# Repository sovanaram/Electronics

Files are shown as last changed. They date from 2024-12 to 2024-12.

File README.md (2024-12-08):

# Isolated Pure Sine Wave Single Phase Inverter using SPWM
this topic is about How to make Inverter by your self and These are the steps to makes it:
1, Researching theories of Inverter 
2, Select Topology (DCDC Converter stage, Inverter stage)
3, Calculating DCDC Converter and Inverter
4, Calculating Transformer and Inductors of DCDC Converter
5, Design Transformer and Inductors 
6, Design schematic and PCB 
7, Installing Hardware 
8, Select electronic switches(MOSFETs and DIODEs)
9, Select Controller
10, Programming and choose the types of Closed loop Control Methods, Filter
11, Testing Hardware

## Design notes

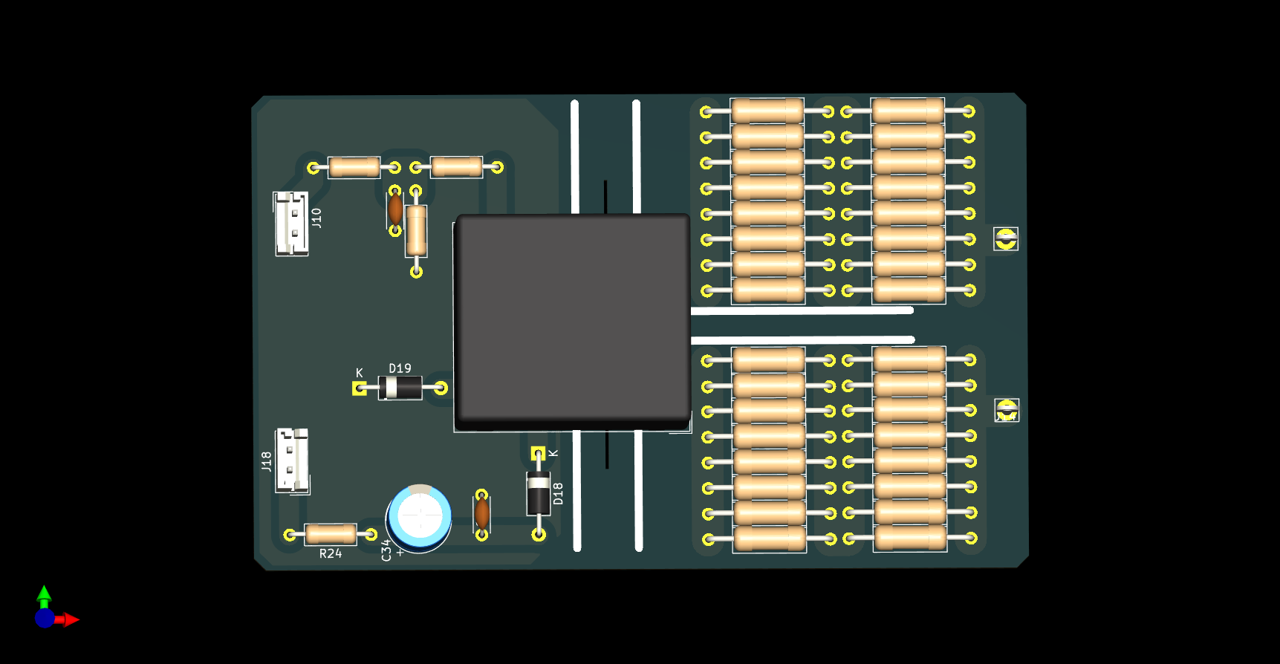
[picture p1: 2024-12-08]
Voltage Sensor/Voltage Sensor.png

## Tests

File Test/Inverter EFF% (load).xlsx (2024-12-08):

No. | Vin(V) | Iin(A) | Pin(W) | Vout(V) | Iout(A) | Pout(W) | PF | EFF%
1 | 50.5 | 0.51 | 25.755 | 224 | 0 | 0 | 1 | 0
2 | 50.23 | 0.79 | 39.6817 | 224 | 0.04553571429 | 10.2 | 1 | 25.70454391 |  |  |  |  | No. | Vo(AC) | Po(INV) W | Pin(INV) W | PF | Pin(DC) W | Vin(DC) V | EFF%(INV) | EFF%(DC) | EFF%(Tot)
3 | 49.97 | 0.81 | 40.4757 | 224.5 | 0.05033407572 | 11.3 | 1 | 27.91798536 |  |  |  | No Load | 1 | 224 | 0 | 6.8 | 0 | 27.28 | 49.6 | 0 | 24.92668622 | 0
4 | 49.95 | 0.87 | 43.4565 | 224.53 | 0.08301785953 | 18.64 | 1 | 42.89346818 |  |  |  | pho.CH+LED | 2 | 224 | 11.5 | 18.8 | 0.538 | 40.919 | 49.3 | 61.17021277 | 45.94442679 | 28.10430362
5 | 49.92 | 1.01 | 50.4192 | 224.52 | 0.09665063246 | 21.7 | 1 | 43.03915969 |  |  |  | LCR meter | 3 | 224.5 | 13.5 | 20.8 | 0.72 | 42.398 | 49.3 | 64.90384615 | 49.05891787 | 31.84112458
6 | 49.88 | 1.08 | 53.8704 | 224.36 | 0.113210911 | 25.4 | 1 | 47.15019751 |  |  |  | PC Addap | 4 | 224.53 | 17.6 | 24.8 | 0.859 | 47.821 | 49.3 | 70.96774194 | 51.86006148 | 36.8039146
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

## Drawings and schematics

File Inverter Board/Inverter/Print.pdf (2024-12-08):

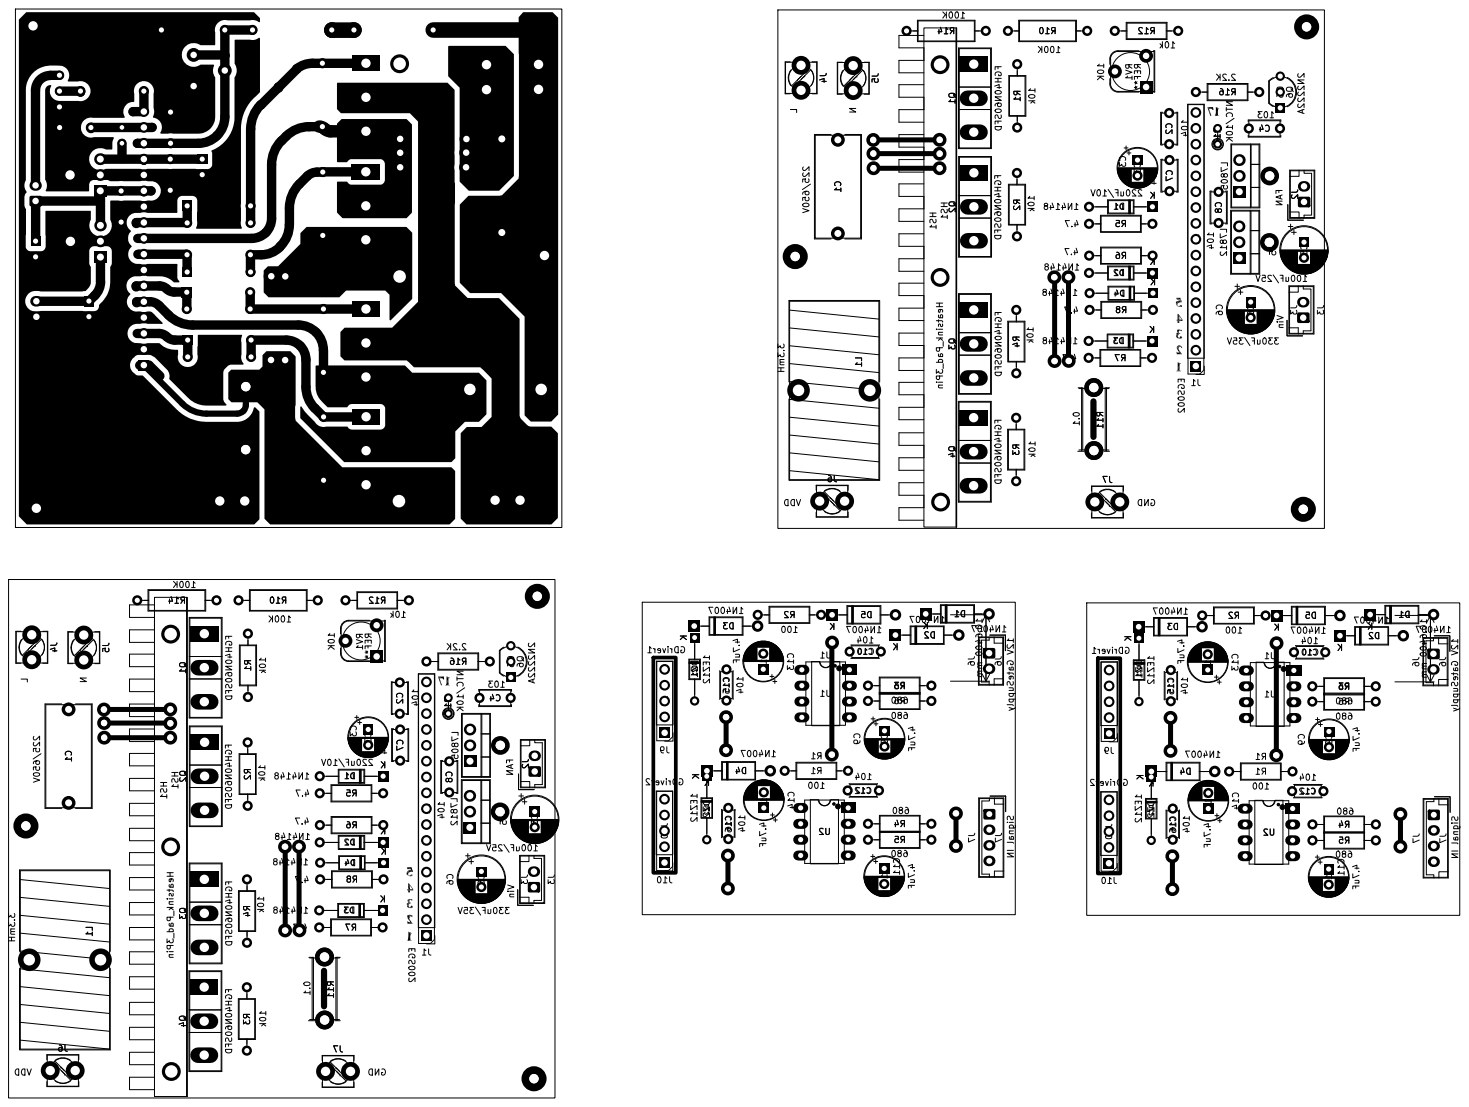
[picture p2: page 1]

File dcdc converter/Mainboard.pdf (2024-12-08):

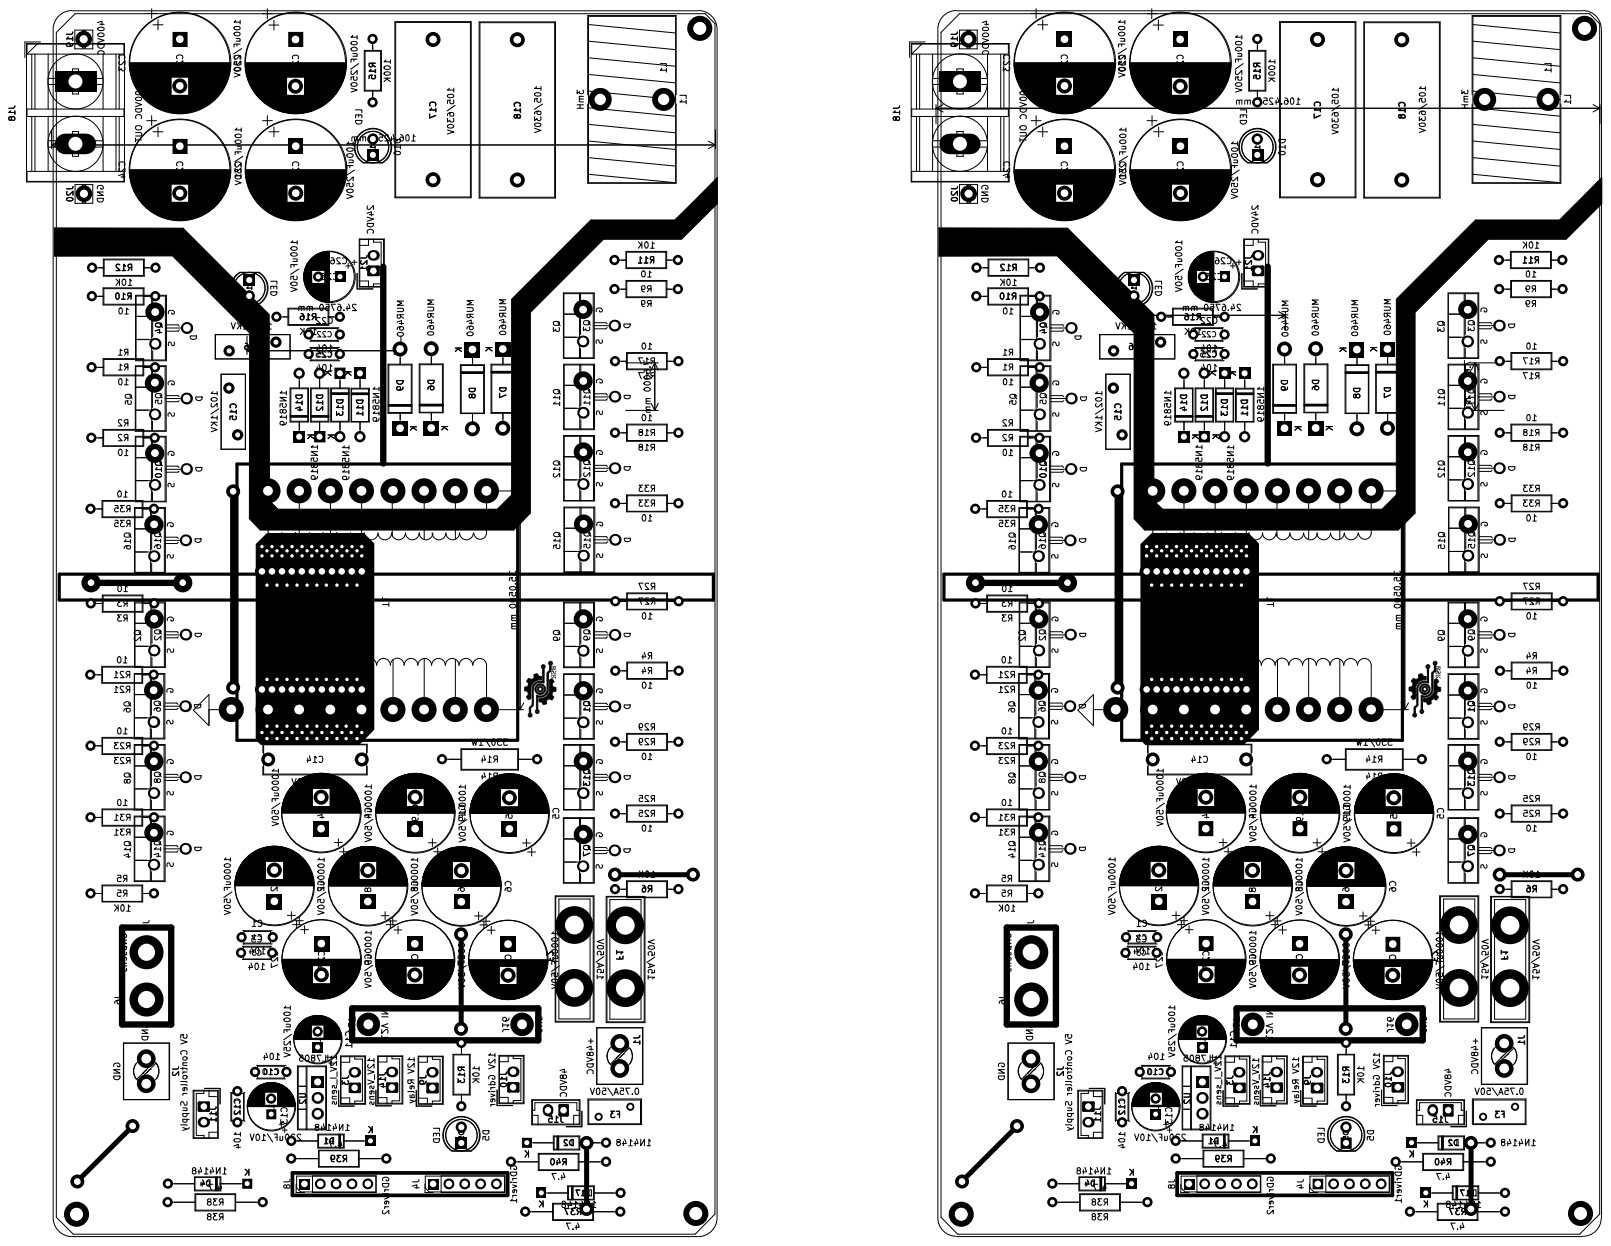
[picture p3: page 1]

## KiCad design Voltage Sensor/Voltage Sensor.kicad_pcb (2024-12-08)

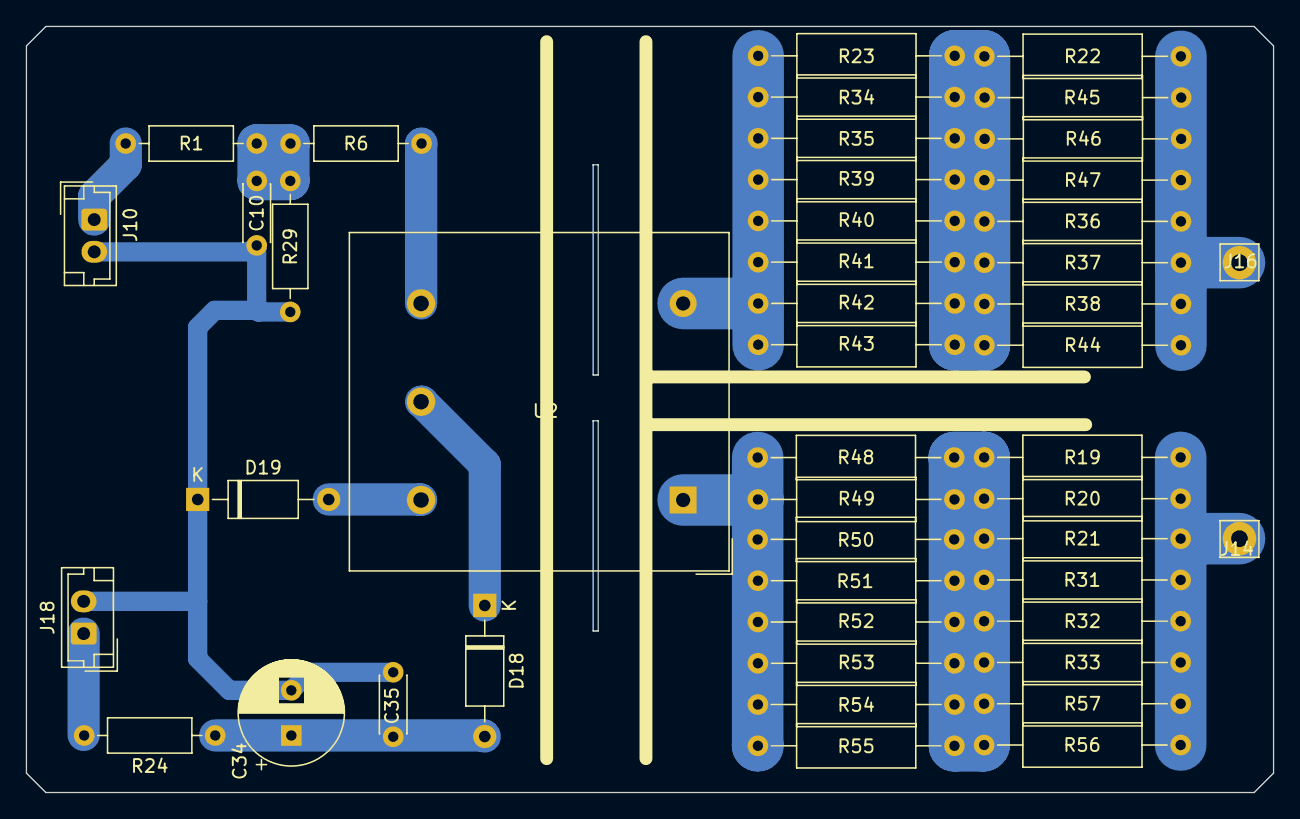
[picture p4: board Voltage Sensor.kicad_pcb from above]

Board: 2 copper layers, 96.7 x 59.4 mm, 46 parts (0 on the bottom side), 4 nets.

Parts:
C10: 102; C_Disc_D4.3mm_W1.9mm_P5.00mm
C34: 100uF/25; CP_Radial_D8.0mm_P3.50mm
C35: 104; C_Disc_D4.3mm_W1.9mm_P5.00mm
D18: 1N4007; D_A-405_P10.16mm_Horizontal
D19: D; D_A-405_P10.16mm_Horizontal
J10: V_sens; JST_EH_B2B-EH-A_1x02_P2.50mm_Vertical
J14: 400VDC; Pin_D1.3mm_L11.3mm_W2.8mm_Flat
J16: GND; Pin_D1.3mm_L11.3mm_W2.8mm_Flat
J18: 12V_Vsens; JST_EH_B2B-EH-A_1x02_P2.50mm_Vertical
R1: 330; R_Axial_DIN0207_L6.3mm_D2.5mm_P10.16mm_Horizontal
R6, R29: 1K; R_Axial_DIN0207_L6.3mm_D2.5mm_P10.16mm_Horizontal
R19, R20, R21, R22, R23, R31, R32, R33, R34, R35, R36, R37, R38, R39, R40, R41, R42, R43, R44, R45, R46, R47, R48, R49, R50, R51, R52, R53, R54, R55, R56, R57: 100k; R_Axial_DIN0309_L9.0mm_D3.2mm_P15.24mm_Horizontal
R24: 100; R_Axial_DIN0207_L6.3mm_D2.5mm_P10.16mm_Horizontal
U2: LV25-P; LEM_LV25-P

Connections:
+12V: J18.1, R24.2
/+400VDC: J14.1, R19.2, R20.2, R21.2, R31.2, R32.2, R33.2, R56.2, R57.2
GND: C10.2, C34.2, C35.2, D19.1 (K), J10.2, J18.2, R29.1
GND1: J16.1, R22.2, R36.2, R37.2, R38.2, R44.2, R45.2, R46.2, R47.2

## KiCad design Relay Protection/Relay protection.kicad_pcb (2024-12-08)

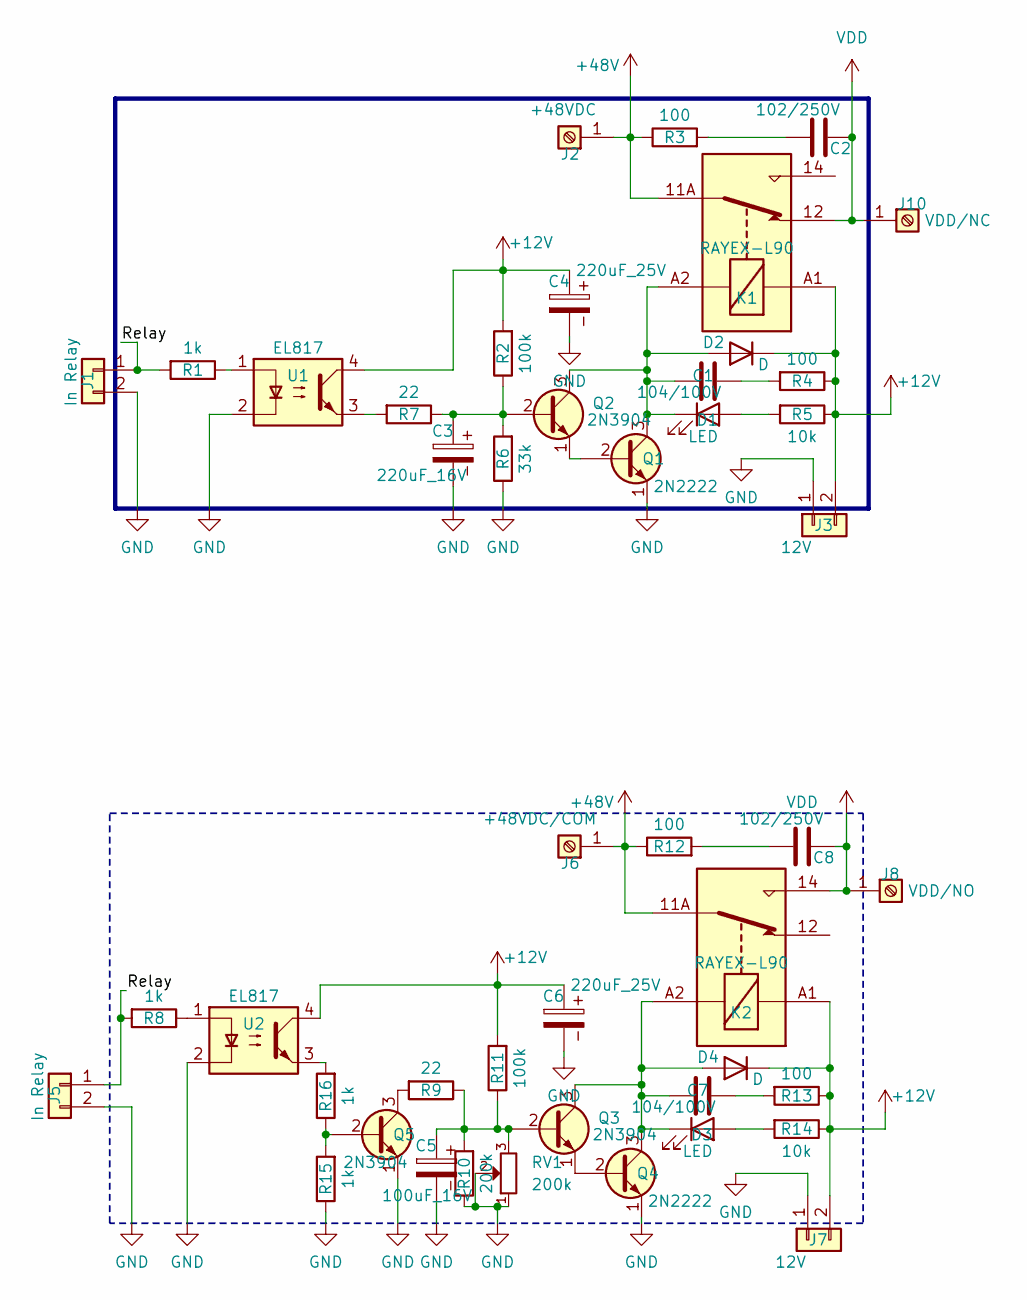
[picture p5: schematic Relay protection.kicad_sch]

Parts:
C1, C7: 104/100V; C_Disc_D6.0mm_W2.5mm_P5.00mm
C2, C8: 102/250V; Fuse_BelFuse_0ZRE0016FF_L9.9mm_W3.8mm
C3: 220uF_16V; CP_Radial_D6.3mm_P2.50mm
C4, C6: 220uF_25V; CP_Radial_D6.3mm_P2.50mm
C5: 100uF_16V; CP_Radial_D6.3mm_P2.50mm
D1, D3: LED; LED_D5.0mm_Clear
D2, D4: D; D_A-405_P10.16mm_Horizontal
J1, J5: In Relay; JST_EH_B2B-EH-A_1x02_P2.50mm_Vertical
J2: +48VDC; TerminalBlock_MetzConnect_360291_1x01_Horizontal_ScrewM3.0_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
J3, J7: 12V; JST_EH_B2B-EH-A_1x02_P2.50mm_Vertical
J6: +48VDC/COM; TerminalBlock_MetzConnect_360291_1x01_Horizontal_ScrewM3.0_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
J8: VDD/NO; TerminalBlock_MetzConnect_360291_1x01_Horizontal_ScrewM3.0_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
J10: VDD/NC; TerminalBlock_MetzConnect_360291_1x01_Horizontal_ScrewM3.0_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
K1, K2: RAYEX-L90; Relay_SPDT_RAYEX-L90
Q1, Q4: 2N2222; TO-92_Inline_Wide
Q2, Q3, Q5: 2N3904; TO-92L_Inline_Wide
R1, R8, R15, R16: 1k; R_Axial_DIN0207_L6.3mm_D2.5mm_P10.16mm_Horizontal
R2, R11: 100k; R_Axial_DIN0207_L6.3mm_D2.5mm_P10.16mm_Horizontal
R3, R4, R12, R13: 100; R_Axial_DIN0207_L6.3mm_D2.5mm_P10.16mm_Horizontal
R5, R14: 10k; R_Axial_DIN0207_L6.3mm_D2.5mm_P10.16mm_Horizontal
R6: 33k; R_Axial_DIN0207_L6.3mm_D2.5mm_P10.16mm_Horizontal
R7, R9: 22; R_Axial_DIN0207_L6.3mm_D2.5mm_P10.16mm_Horizontal
R10: 200k; R_Axial_DIN0207_L6.3mm_D2.5mm_P10.16mm_Horizontal
RV1: 200k; Potentiometer_RM065
U1, U2: EL817; DIP-4_W7.62mm

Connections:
+12V: C4.1, C6.1, D2.1 (K), D4.1 (K), J3.2, J7.2, K1.A1, K2.A1, R2.2, R4.1, R5.1, R11.2, R13.1, R14.1, U1.4, U2.4
+48V: J2.1, J6.1, K1.11A, K1.11B, K2.11A, K2.11B, R3.1, R12.1
/Relay: J1.1, J5.1, R1.2, R8.2
GND: C3.2, C4.2, C5.2, C6.2, J1.2, J3.1, J5.2, J7.1, Q1.1 (E), Q4.1 (E), Q5.1 (E), R6.1, R10.1, R15.1, RV1.1, RV1.2, U1.2, U2.2
unnamed: C1.1, R4.2
unnamed: C2.1, R3.2
unnamed: C7.1, R13.2
unnamed: C8.1, R12.2
unnamed: D1.2 (A), R5.2
unnamed: C1.2, D1.1 (K), D2.2 (A), K1.A2, Q1.3 (C), Q2.3 (C)
unnamed: D3.2 (A), R14.2
unnamed: C7.2, D3.1 (K), D4.2 (A), K2.A2, Q3.3 (C), Q4.3 (C)
unnamed: Q1.2 (B), Q2.1 (E)
unnamed: C3.1, Q2.2 (B), R2.1, R6.2, R7.1
unnamed: C5.1, Q3.2 (B), R9.1, R10.2, R11.1, RV1.3
unnamed: Q3.1 (E), Q4.2 (B)
unnamed: Q5.2 (B), R15.2, R16.1
unnamed: Q5.3 (C), R9.2
unnamed: R1.1, U1.1
unnamed: R7.2, U1.3
unnamed: R8.1, U2.1
unnamed: R16.2, U2.3
VDD: C2.2, C8.2, J8.1, J10.1, K1.12, K2.14

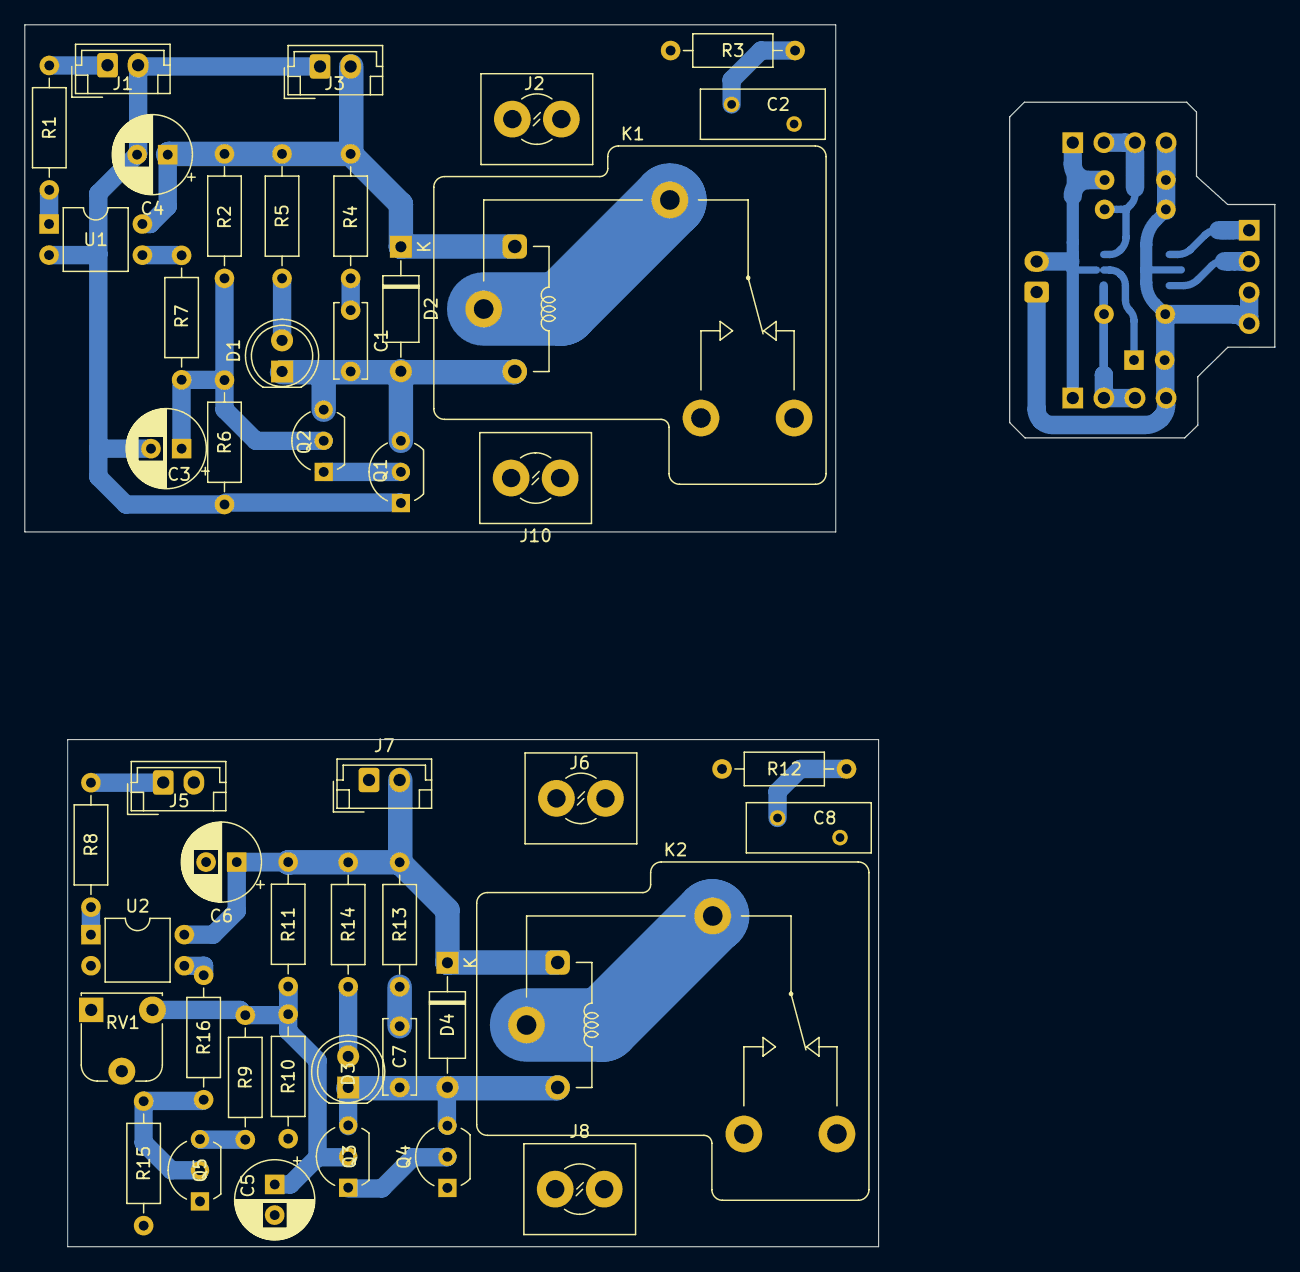
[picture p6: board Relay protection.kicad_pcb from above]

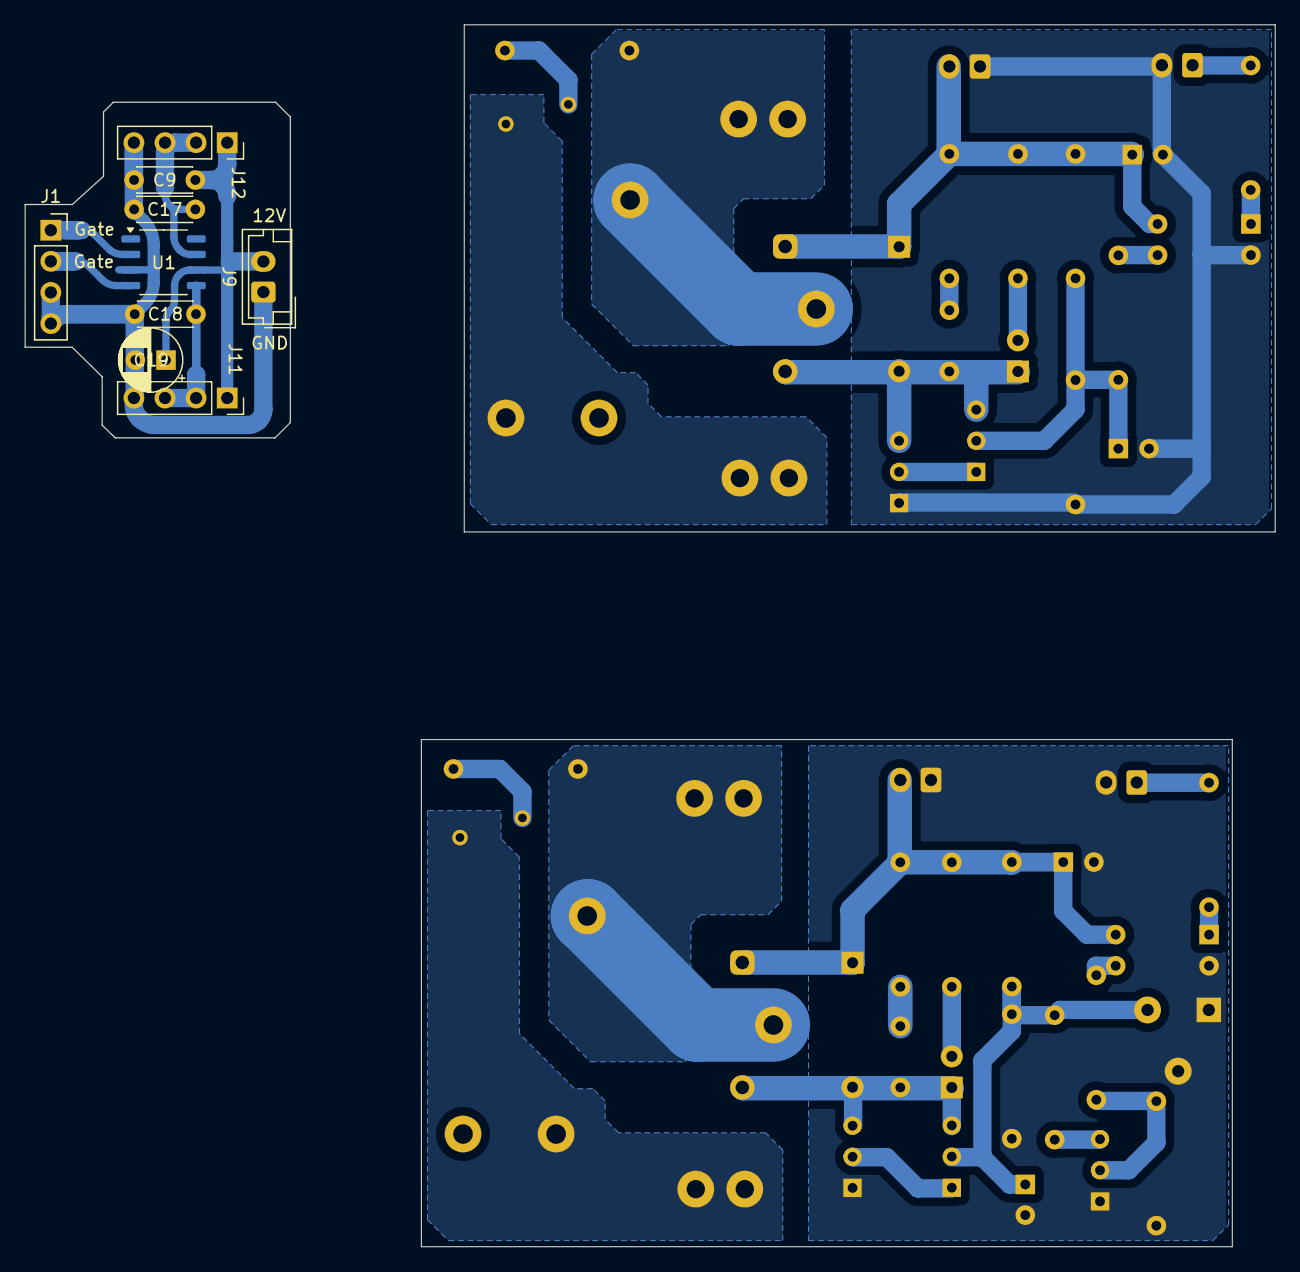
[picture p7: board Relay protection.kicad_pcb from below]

Board: 2 copper layers, 102.1 x 99.8 mm, 55 parts (9 on the bottom side), 23 nets.

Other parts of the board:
C9: 104; C_Disc_D4.3mm_W1.9mm_P5.00mm
C17, C18: 102; C_Disc_D4.3mm_W1.9mm_P5.00mm
C19: 10uF/50V; CP_Radial_D5.0mm_P2.50mm
J1#2, J11, J12: Conn_01x04; PinSocket_1x04_P2.54mm_Vertical
J9: 12V Gdriver; JST_EH_B2B-EH-A_1x02_P2.50mm_Vertical
U1#2: IRS4427S; SSOP-8_3.9x5.05mm_P1.27mm

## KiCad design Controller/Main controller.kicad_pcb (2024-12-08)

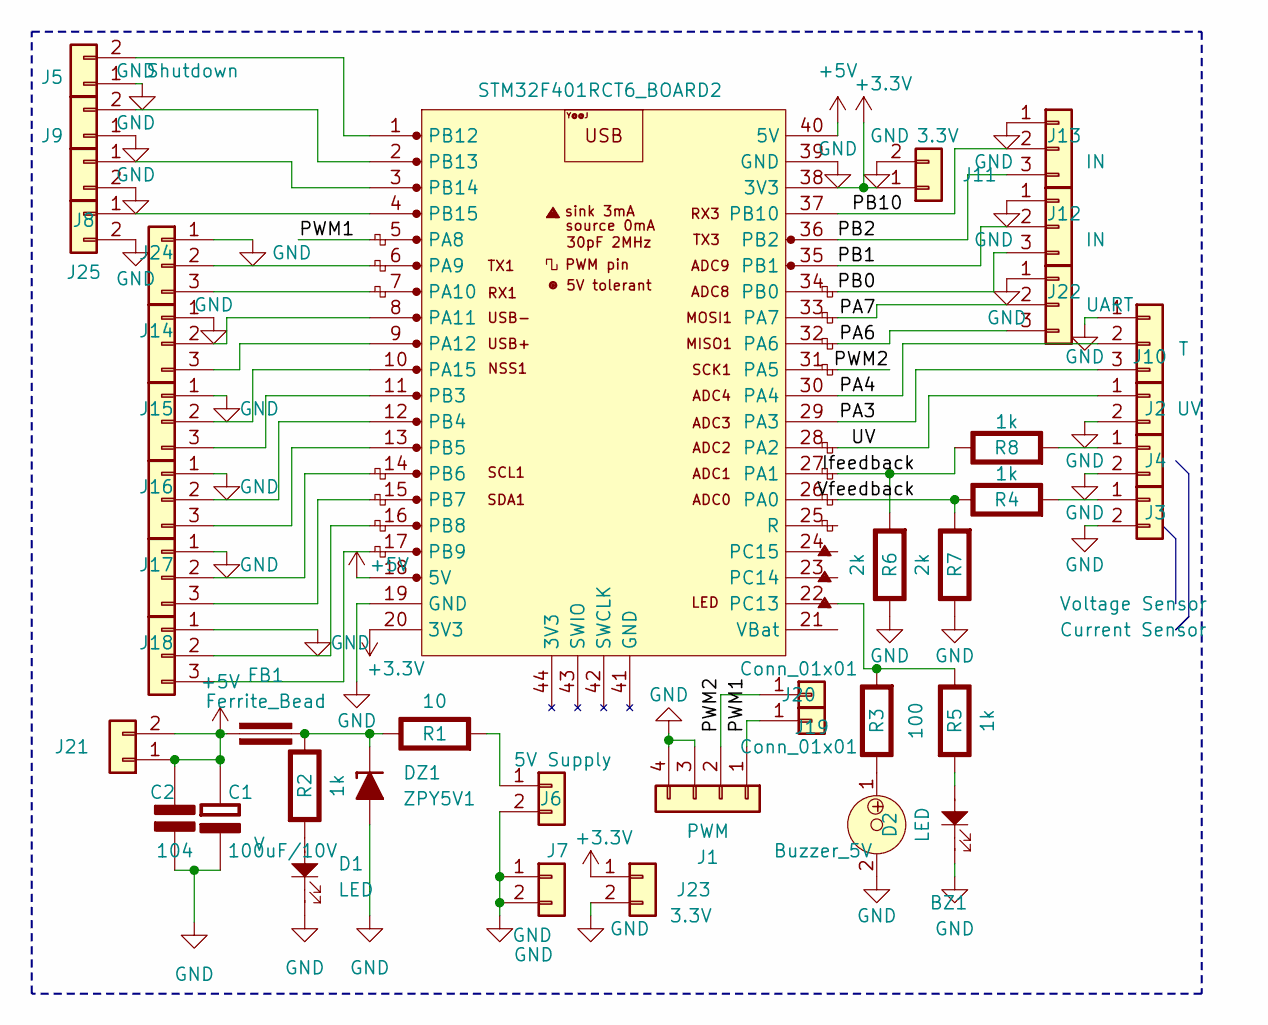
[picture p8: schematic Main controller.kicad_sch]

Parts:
BZ1: Buzzer_5V; MagneticBuzzer_ProSignal_ABT-410-RC
C1: 100uF/10V; CP_Radial_D7.5mm_P2.50mm; Rating V
C2: 104; C_Disc_D5.0mm_W2.5mm_P5.00mm; Rating V
D1, D2: LED; LED_D5.0mm
DZ1: ZPY5V1; D_DO-34_SOD68_P7.62mm_Horizontal
FB1: Ferrite_Bead; L_Axial_L7.0mm_D3.3mm_P5.08mm_Vertical_Fastron_MICC
J1: PWM; JST_EH_B4B-EH-A_1x04_P2.50mm_Vertical
J2: UV; JST_EH_B2B-EH-A_1x02_P2.50mm_Vertical
J3: Voltage Sensor; JST_EH_B2B-EH-A_1x02_P2.50mm_Vertical
J4: Current Sensor; JST_EH_B2B-EH-A_1x02_P2.50mm_Vertical
J5: Shutdown; JST_EH_B2B-EH-A_1x02_P2.50mm_Vertical
J6: 5V Supply; JST_EH_B2B-EH-A_1x02_P2.50mm_Vertical
J7: GND; JST_EH_B2B-EH-A_1x02_P2.50mm_Vertical
J8, J9, J21, J25: JST_EH_B2B-EH-A_1x02_P2.50mm_Vertical
J10: T; JST_EH_B3B-EH-A_1x03_P2.50mm_Vertical
J11, J23: 3.3V; JST_EH_B2B-EH-A_1x02_P2.50mm_Vertical
J12, J13: IN; JST_EH_B3B-EH-A_1x03_P2.50mm_Vertical
J14, J15, J16, J17, J18, J24: JST_EH_B3B-EH-A_1x03_P2.50mm_Vertical
J19, J20: Conn_01x01; PinSocket_1x01_P2.54mm_Vertical
J22: UART; JST_EH_B3B-EH-A_1x03_P2.50mm_Vertical
R1: 10; R_Axial_DIN0207_L6.3mm_D2.5mm_P10.16mm_Horizontal; Rating W
R2, R4, R5, R8: 1k; R_Axial_DIN0207_L6.3mm_D2.5mm_P10.16mm_Horizontal; Rating W
R3: 100; R_Axial_DIN0207_L6.3mm_D2.5mm_P10.16mm_Horizontal; Rating W
R6, R7: 2k; R_Axial_DIN0207_L6.3mm_D2.5mm_P10.16mm_Horizontal; Rating W
STM32F401RCT6_BOARD2: STM32F401RCT6_BOARD1

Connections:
+5V: C1.1 (+), C2.1 (+), FB1.1, J21.1, J21.2, STM32F401RCT6_BOARD2.18 (5V), STM32F401RCT6_BOARD2.40 (5V)
/Ifeedback: R6.2 (-), R8.1 (+), STM32F401RCT6_BOARD2.27 (PA1)
/PA3: J10.3, STM32F401RCT6_BOARD2.29 (PA3)
/PA4: J10.2, STM32F401RCT6_BOARD2.30 (PA4)
/PA6: J22.3, STM32F401RCT6_BOARD2.32 (PA6)
/PA7: J22.2, STM32F401RCT6_BOARD2.33 (PA7)
/PB0: J12.3, STM32F401RCT6_BOARD2.34 (PB0)
/PB1: J12.2, STM32F401RCT6_BOARD2.35 (PB1)
/PB2: J13.3, STM32F401RCT6_BOARD2.36 (PB2)
/PB10: J13.2, STM32F401RCT6_BOARD2.37 (PB10)
/PWM1: J1.1, J19.1, STM32F401RCT6_BOARD2.5 (PA8)
/PWM2: J1.2, J20.1, STM32F401RCT6_BOARD2.31 (PA5)
/UV: J2.1, STM32F401RCT6_BOARD2.28 (PA2)
/Vfeedback: R4.1 (+), R7.2 (-), STM32F401RCT6_BOARD2.26 (PA0)
GND: BZ1.2, C1.2 (-), C2.2 (-), D1.1, D2.1, DZ1.2 (A), J1.3, J1.4, J2.2, J3.2, J4.2, J5.1, J6.2, J7.1, J7.2, J8.2, J9.1, J10.1, J11.2, J12.1, J13.1, J14.1, J15.1, J16.1, J17.1, J18.1, J22.1, J23.2, J24.1, J25.2, R6.1 (+), R7.1 (+), STM32F401RCT6_BOARD2.19 (GND), STM32F401RCT6_BOARD2.39 (GND)
unnamed: DZ1.1 (K), FB1.2, R1.1 (+), R2.1 (+)
unnamed: J3.1, R4.2 (-)
unnamed: J4.1, R8.2 (-)
unnamed: J5.2, STM32F401RCT6_BOARD2.1 (PB12)
unnamed: J6.1, R1.2 (-)
unnamed: J8.1, STM32F401RCT6_BOARD2.3 (PB14)
unnamed: J9.2, STM32F401RCT6_BOARD2.2 (PB13)
unnamed: J14.2, STM32F401RCT6_BOARD2.8 (PA11)
unnamed: J14.3, STM32F401RCT6_BOARD2.9 (PA12)
unnamed: J15.2, STM32F401RCT6_BOARD2.10 (PA15)
unnamed: J15.3, STM32F401RCT6_BOARD2.11 (PB3)
unnamed: J16.2, STM32F401RCT6_BOARD2.12 (PB4)
unnamed: J16.3, STM32F401RCT6_BOARD2.13 (PB5)
unnamed: J17.2, STM32F401RCT6_BOARD2.14 (PB6)
unnamed: J17.3, STM32F401RCT6_BOARD2.15 (PB7)
unnamed: J18.2, STM32F401RCT6_BOARD2.16 (PB8)
unnamed: J18.3, STM32F401RCT6_BOARD2.17 (PB9)
unnamed: J24.2, STM32F401RCT6_BOARD2.6 (PA9)
unnamed: J24.3, STM32F401RCT6_BOARD2.7 (PA10)
unnamed: J25.1, STM32F401RCT6_BOARD2.4 (PB15)
unnamed: D1.2, R2.2 (-)
unnamed: BZ1.1, R3.1 (+)
unnamed: R3.2 (-), R5.1 (+), STM32F401RCT6_BOARD2.22 (PC13)
unnamed: D2.2, R5.2 (-)

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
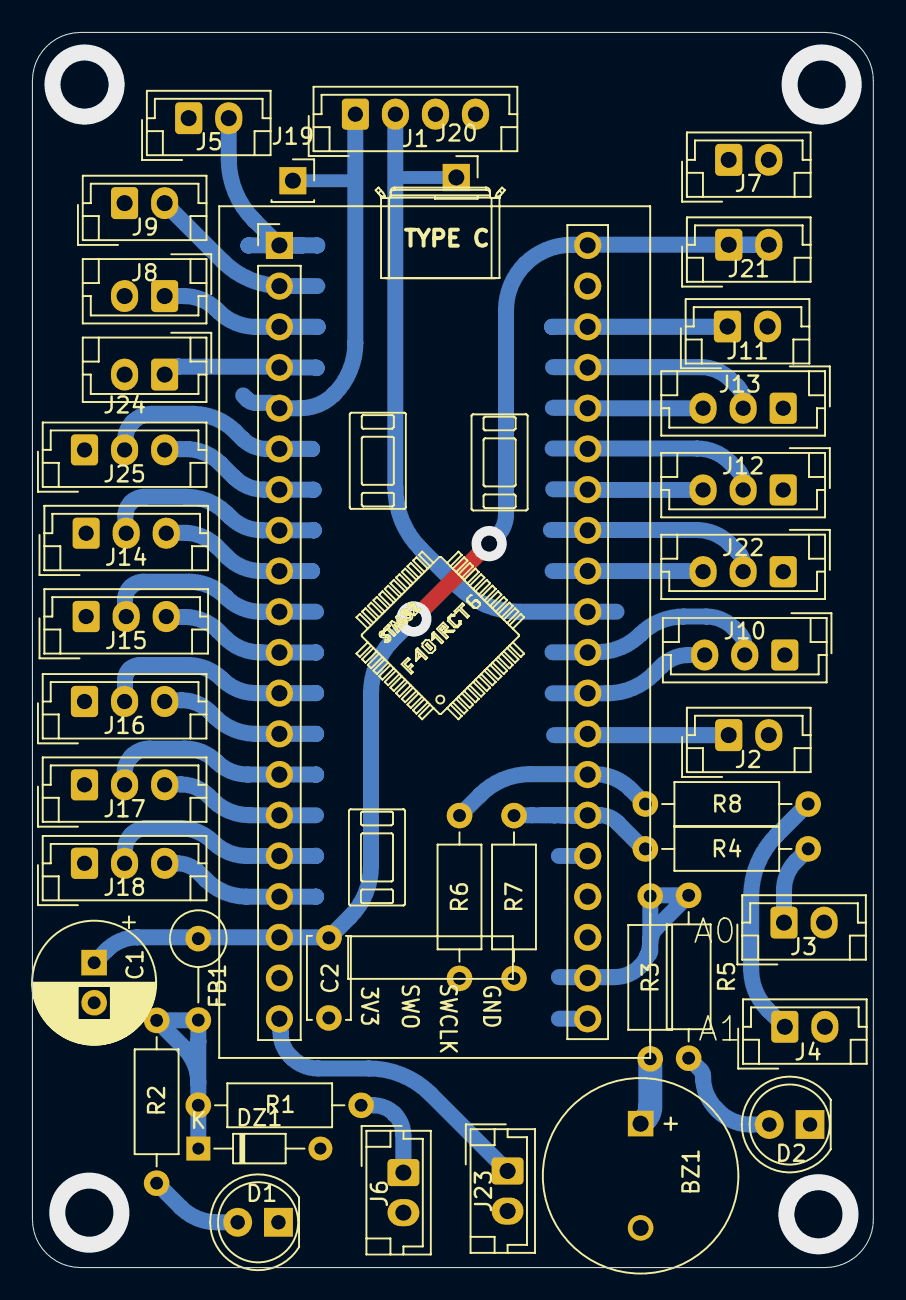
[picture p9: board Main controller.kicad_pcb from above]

Board: 2 copper layers, 52.5 x 77.1 mm, 41 parts (0 on the bottom side), 41 nets.

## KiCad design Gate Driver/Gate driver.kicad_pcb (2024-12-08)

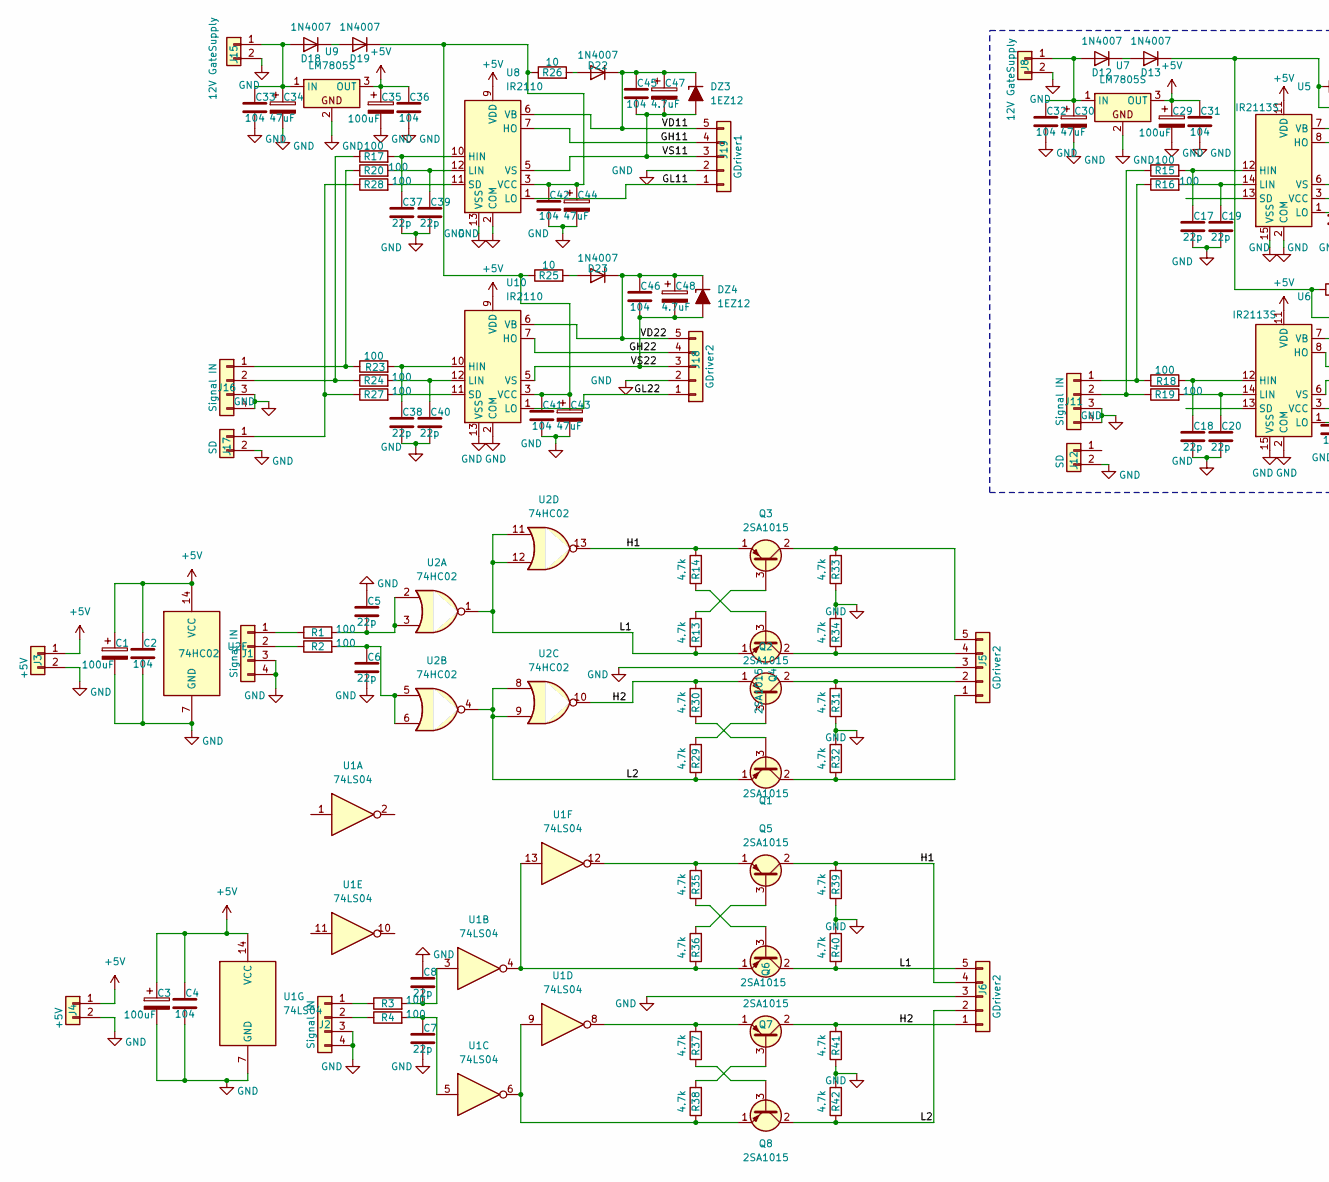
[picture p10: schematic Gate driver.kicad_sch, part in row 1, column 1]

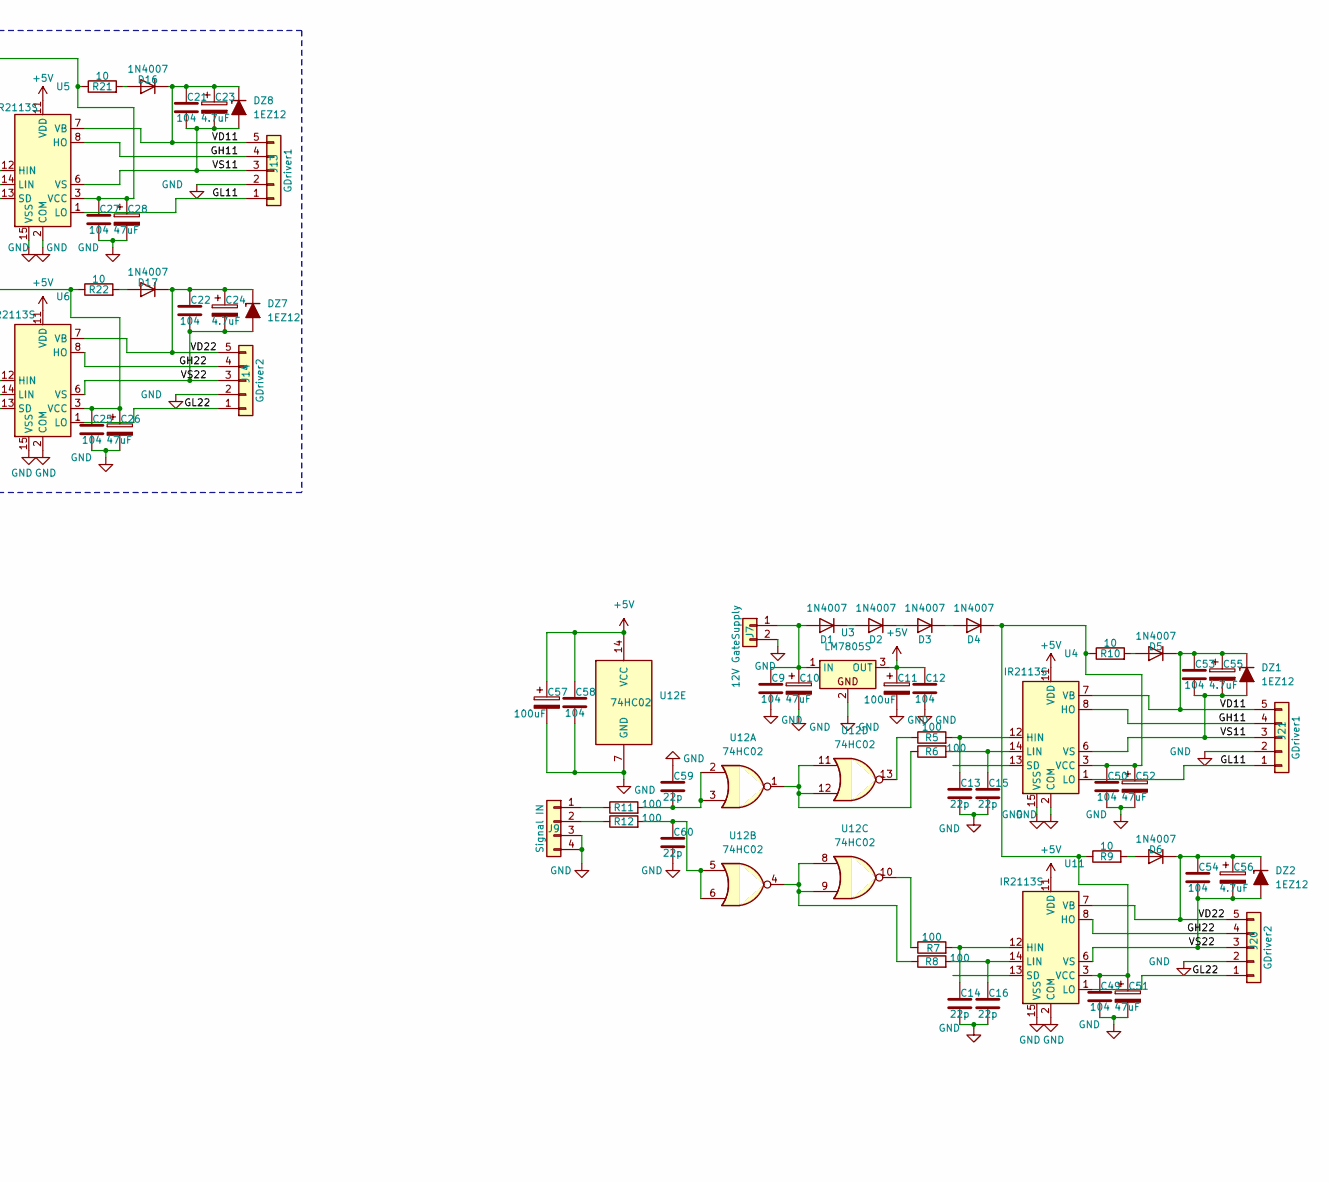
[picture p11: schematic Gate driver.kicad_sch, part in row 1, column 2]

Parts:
C1, C3, C11, C29, C35, C57: 100uF; CP_Radial_D6.3mm_P2.50mm
C2, C4, C9, C12, C21, C22, C25, C27, C31, C32, C33, C36, C41, C42, C45, C46, C49, C50, C53, C54, C58: 104; C_Disc_D4.3mm_W1.9mm_P5.00mm
C5, C6, C7, C8, C13, C14, C15, C16, C17, C18, C19, C20, C37, C38, C39, C40, C59, C60: 22p; C_Disc_D4.3mm_W1.9mm_P5.00mm
C10, C26, C28, C30, C34, C43, C44, C51, C52: 47uF; CP_Radial_D6.3mm_P2.50mm
C23, C24, C47, C48, C55, C56: 4.7uF; CP_Radial_D6.3mm_P2.50mm
D1, D2, D3, D4, D5, D6, D12, D13, D16, D17, D18, D19, D22, D23: 1N4007; D_SMA
DZ1, DZ2, DZ3, DZ4, DZ7, DZ8: 1EZ12; D_DO-34_SOD68_P10.16mm_Horizontal
J1, J2, J9, J11, J16: Signal IN; JST_EH_B4B-EH-A_1x04_P2.50mm_Vertical
J3, J4: +5V; JST_EH_B2B-EH-A_1x02_P2.50mm_Vertical
J5, J6, J14, J18, J20: GDriver2; PinSocket_1x05_P2.54mm_Vertical
J7, J8, J15: 12V GateSupply; JST_EH_B2B-EH-A_1x02_P2.50mm_Vertical
J12, J17: SD; JST_EH_B2B-EH-A_1x02_P2.50mm_Vertical
J13, J19, J21: GDriver1; PinSocket_1x05_P2.54mm_Vertical
Q1, Q2, Q3, Q4, Q5, Q6, Q7, Q8: 2SA1015; TO-92_Inline_Wide_ECB
R1, R2, R3, R4, R5, R6, R7, R8, R11, R12, R15, R16, R17, R18, R19, R20, R23, R24, R27, R28: 100; R_Axial_DIN0207_L6.3mm_D2.5mm_P10.16mm_Horizontal
R9, R10, R21, R22, R25, R26: 10; R_1210_3225Metric_Pad1.30x2.65mm_HandSolder
R13, R14, R29, R30, R31, R32, R33, R34, R35, R36, R37, R38, R39, R40, R41, R42: 4.7k; R_Axial_DIN0207_L6.3mm_D2.5mm_P10.16mm_Horizontal
U1: 74LS04; DIP-14_W7.62mm_LongPads
U2, U12: 74HC02; DIP-14_W7.62mm_LongPads
U3, U7: LM7805S; TO-252-2
U4, U5, U6, U11: IR2113S; SOIC-16W_7.5x10.3mm_P1.27mm
U8, U10: IR2110; DIP-14_W7.62mm
U9: LM7805S; TO-263-3_TabPin2

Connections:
+5V: C1.1, C2.1, C3.1, C4.1, C11.1, C12.1, C29.1, C31.1, C35.1, C36.1, C57.1, C58.1, J3.1, J4.1, U1.14 (VCC), U2.14 (VCC), U3.3 (OUT), U4.11 (VDD), U5.11 (VDD), U6.11 (VDD), U7.3 (OUT), U8.9 (VDD), U9.3 (OUT), U10.9 (VDD), U11.11 (VDD), U12.14 (VCC)
/GH11: J13.4, J19.4, J21.4, U4.8 (HO), U5.8 (HO), U8.7 (HO)
/GH22: J14.4, J18.4, J20.4, U6.8 (HO), U10.7 (HO), U11.8 (HO)
/GL11: J13.1, J19.1, J21.1, U4.1 (LO), U5.1 (LO), U8.1 (LO)
/GL22: J14.1, J18.1, J20.1, U6.1 (LO), U10.1 (LO), U11.1 (LO)
/H1: J6.4, Q3.1 (E), Q5.2 (C), R14.2, R39.2, U2.13
/H2: J6.1, Q2.1 (E), Q7.2 (C), R30.2, R41.2, U2.10
/L1: J6.5, Q4.1 (E), Q6.2 (C), R13.1, R40.1, U2.1, U2.11, U2.12
/L2: J6.2, Q1.1 (E), Q8.2 (C), R29.1, R42.1, U2.4, U2.8, U2.9
/VD11: C21.1, C23.1, C45.1, C47.1, C53.1, C55.1, D5.1 (K), D16.1 (K), D22.1 (K), DZ1.1 (K), DZ3.1 (K), DZ8.1 (K), J13.5, J19.5, J21.5, U4.7 (VB), U5.7 (VB), U8.6 (VB)
/VS11: C21.2, C23.2, C45.2, C47.2, C53.2, C55.2, DZ1.2 (A), DZ3.2 (A), DZ8.2 (A), J13.3, J19.3, J21.3, U4.6 (VS), U5.6 (VS), U8.5 (VS)
GND: C1.2, C2.2, C3.2, C4.2, C5.1, C6.2, C7.2, C8.1, C9.2, C10.2, C11.2, C12.2, C13.2, C14.2, C15.2, C16.2, C17.2, C18.2, C19.2, C20.2, C25.2, C26.2, C27.2, C28.2, C29.2, C30.2, C31.2, C32.2, C33.2, C34.2, C35.2, C36.2, C37.2, C38.2, C39.2, C40.2, C41.2, C42.2, C43.2, C44.2, C49.2, C50.2, C51.2, C52.2, C57.2, C58.2, C59.1, C60.2, J1.3, J1.4, J2.3, J2.4, J3.2, J4.2, J5.3, J6.3, J7.2, J8.2, J9.3, J9.4, J11.3, J11.4, J12.2, J13.2, J14.2, J15.2, J16.3, J16.4, J17.2, J18.2, J19.2, J20.2, J21.2, R31.1, R32.2, R33.1, R34.2, R39.1, R40.2, R41.1, R42.2, U1.7 (GND), U2.7 (GND), U3.2, U4.2 (COM), U4.15 (VSS), U5.2 (COM), U5.15 (VSS), U6.2 (COM), U6.15 (VSS), U7.2, U8.2 (COM), U8.13 (VSS), U9.2, U10.2 (COM), U10.13 (VSS), U11.2 (COM), U11.15 (VSS), U12.7 (GND)
unnamed: C5.2, R1.2, U2.2, U2.3
unnamed: C6.1, R2.2, U2.5, U2.6
unnamed: C7.1, R4.2, U1.5
unnamed: C8.2, R3.2, U1.3
unnamed: C59.2, R11.2, U12.2, U12.3
unnamed: C60.1, R12.2, U12.5, U12.6
unnamed: C9.1, C10.1, D1.2 (A), J7.1, U3.1 (IN)
unnamed: D1.1 (K), D2.2 (A)
unnamed: D2.1 (K), D3.2 (A)
unnamed: D3.1 (K), D4.2 (A)
unnamed: C49.1, C50.1, C51.1, C52.1, D4.1 (K), R9.1, R10.1, U4.3 (VCC), U11.3 (VCC)
unnamed: D5.2 (A), R10.2
unnamed: D6.2 (A), R9.2
unnamed: C30.1, C32.1, D12.2 (A), J8.1, U7.1 (IN)
unnamed: D12.1 (K), D13.2 (A)
unnamed: D16.2 (A), R21.2
unnamed: D17.2 (A), R22.2
unnamed: C33.1, C34.1, D18.2 (A), J15.1, U9.1 (IN)
unnamed: D18.1 (K), D19.2 (A)
unnamed: D22.2 (A), R26.2
unnamed: D23.2 (A), R25.2
unnamed: J1.1, R1.1
unnamed: J1.2, R2.1
unnamed: J2.1, R3.1
unnamed: J2.2, R4.1
unnamed: J5.1, Q1.2 (C), R32.1
unnamed: J5.2, Q2.2 (C), R31.2
unnamed: J5.4, Q4.2 (C), R34.1
unnamed: J5.5, Q3.2 (C), R33.2
unnamed: J9.1, R11.1
unnamed: J9.2, R12.1
unnamed: J11.1, R16.1, R18.1
unnamed: J11.2, R15.1, R19.1
unnamed: J16.1, R20.1, R23.1
unnamed: J16.2, R17.1, R24.1
unnamed: J17.1, R27.1, R28.1
unnamed: Q1.3 (B), R30.1
unnamed: Q2.3 (B), R29.2
unnamed: Q3.3 (B), R13.2
unnamed: Q4.3 (B), R14.1
unnamed: Q5.3 (B), R36.2
unnamed: Q5.1 (E), R35.2, U1.12
unnamed: Q6.3 (B), R35.1
unnamed: Q6.1 (E), R36.1, U1.4, U1.13
unnamed: Q7.3 (B), R38.2
unnamed: Q7.1 (E), R37.2, U1.8
unnamed: Q8.3 (B), R37.1
unnamed: Q8.1 (E), R38.1, U1.6, U1.9
unnamed: R5.1, U12.13
unnamed: R6.1, U12.1, U12.11, U12.12
unnamed: R7.1, U12.10
unnamed: R8.1, U12.4, U12.8, U12.9
unnamed: C13.1, R5.2, U4.12 (HIN)
unnamed: C15.1, R6.2, U4.14 (LIN)
unnamed: C17.1, R15.2, U5.12 (HIN)
unnamed: C19.1, R16.2, U5.14 (LIN)
unnamed: C18.1, R18.2, U6.12 (HIN)
unnamed: C20.1, R19.2, U6.14 (LIN)
unnamed: C37.1, R17.2, U8.10 (HIN)
unnamed: C39.1, R20.2, U8.12 (LIN)
unnamed: R28.2, U8.11 (SD)
unnamed: C38.1, R23.2, U10.10 (HIN)
unnamed: C40.1, R24.2, U10.12 (LIN)
unnamed: R27.2, U10.11 (SD)
unnamed: C14.1, R7.2, U11.12 (HIN)
unnamed: C16.1, R8.2, U11.14 (LIN)

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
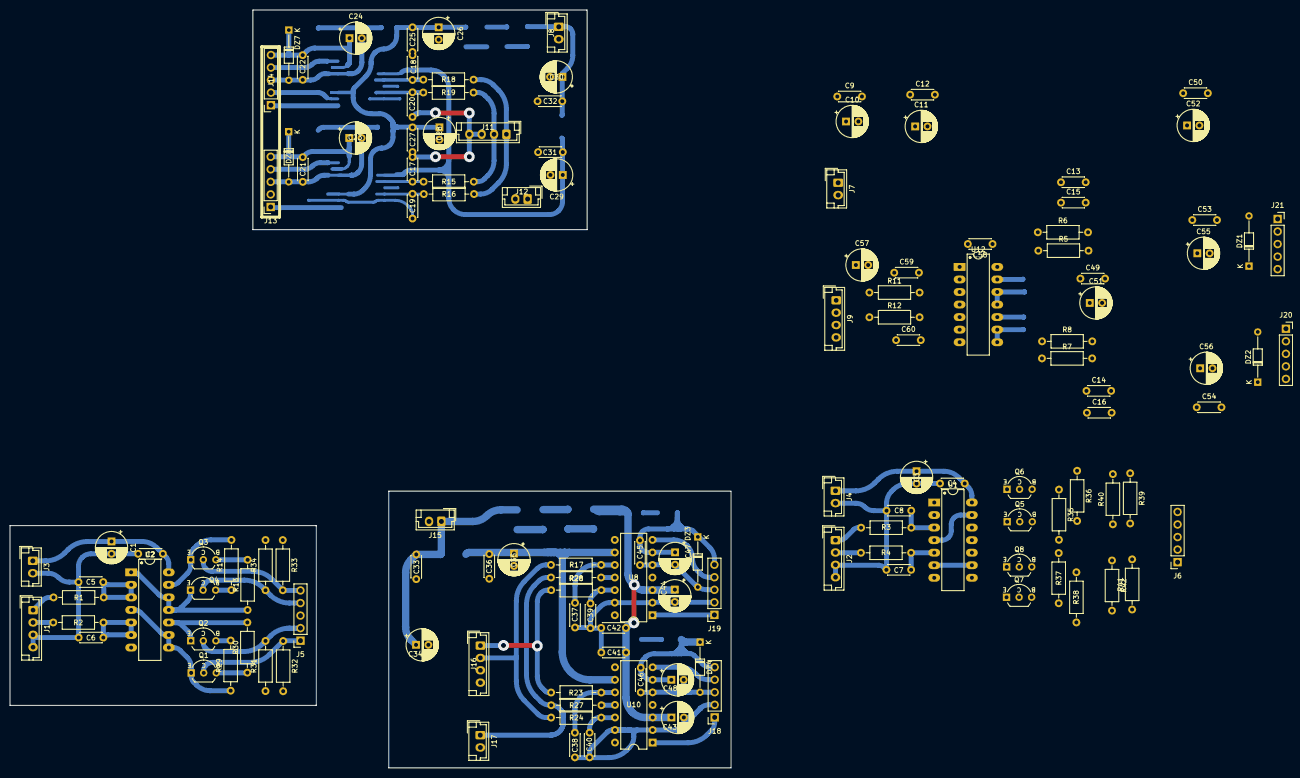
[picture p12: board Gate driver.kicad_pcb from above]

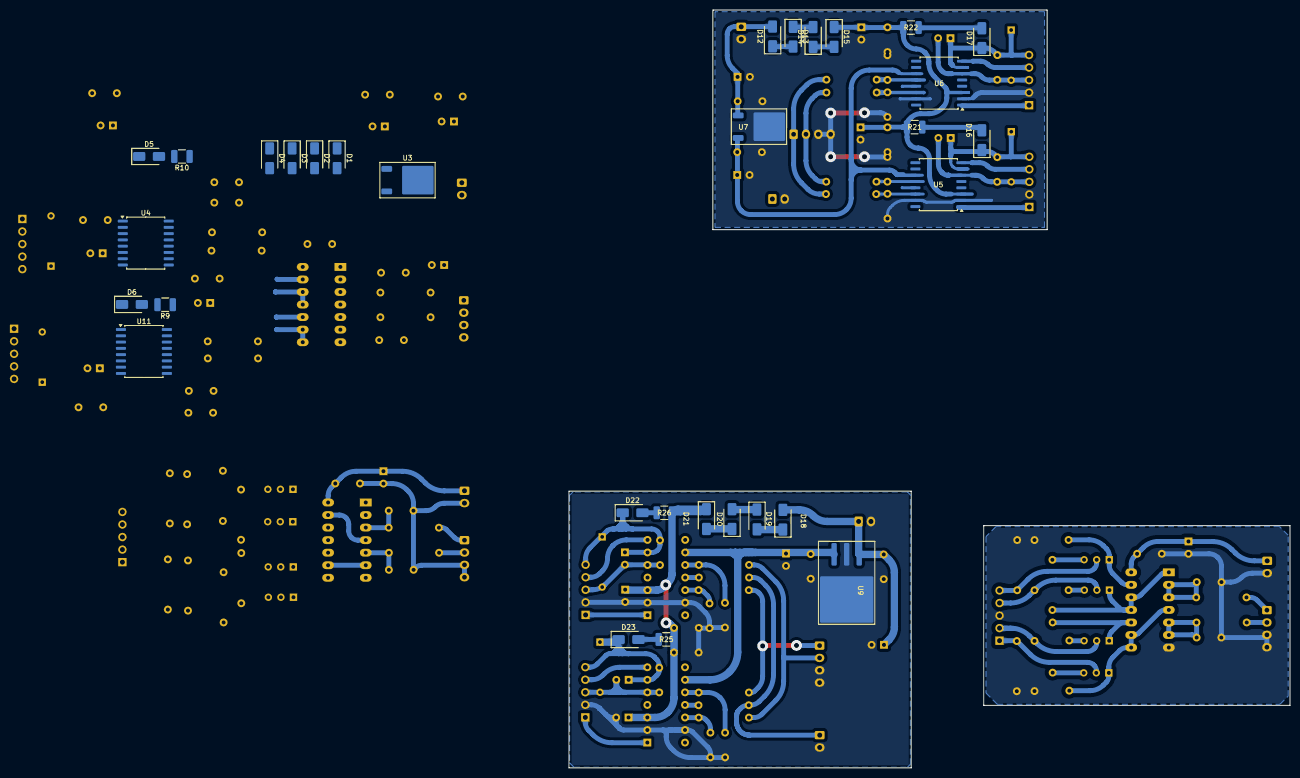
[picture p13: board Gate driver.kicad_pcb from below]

Board: 2 copper layers, 166 parts (31 on the bottom side), 86 nets.

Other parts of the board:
D14, D15, D20, D21: 1N4007; D_SMA

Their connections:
unnamed: D14.1 (K), D15.2 (A)
unnamed: D20.1 (K), D21.2 (A)

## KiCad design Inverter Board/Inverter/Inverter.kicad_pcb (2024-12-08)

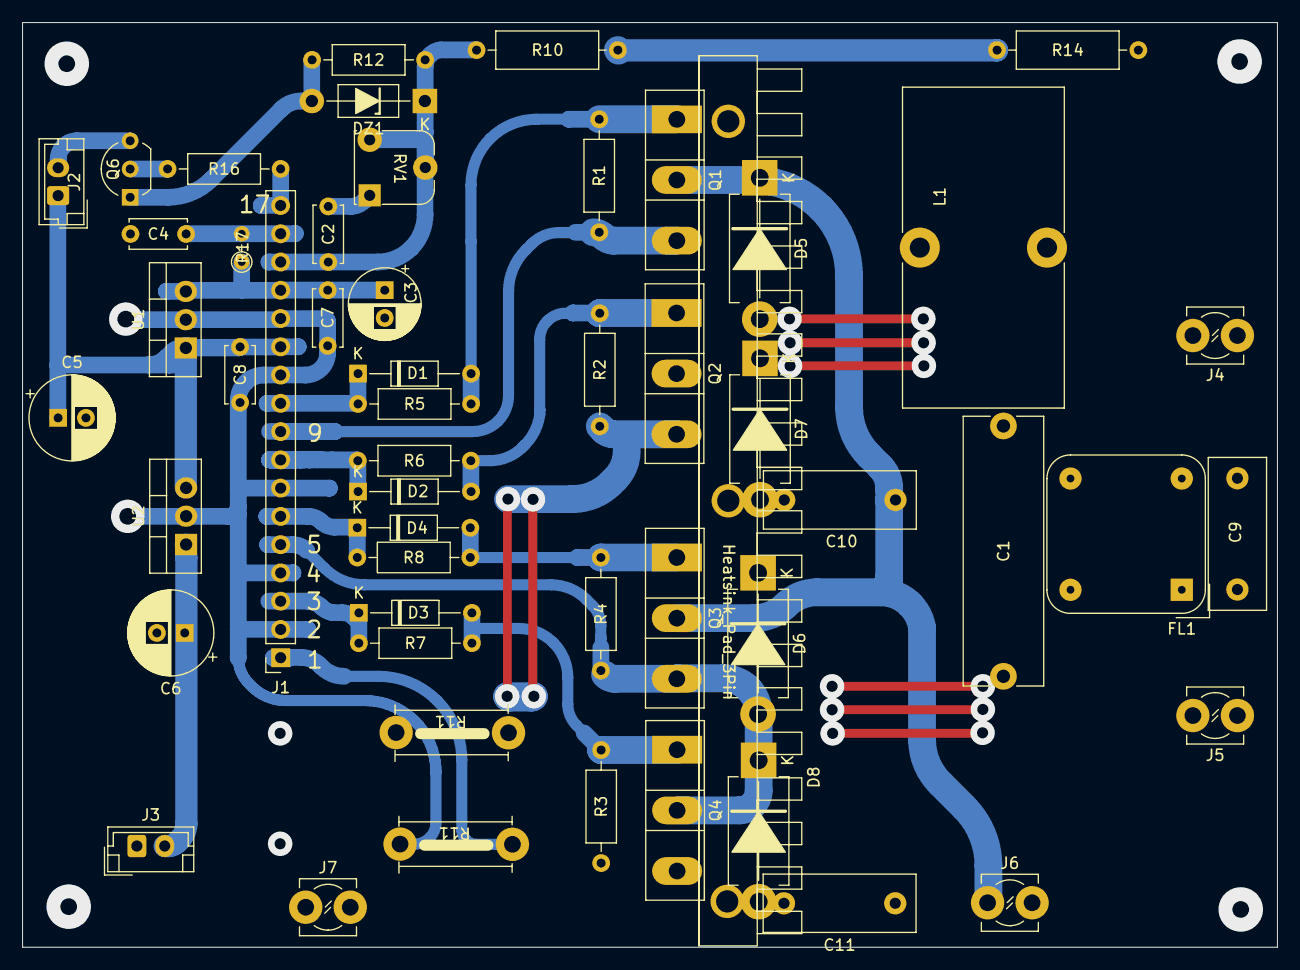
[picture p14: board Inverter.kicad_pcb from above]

Board: 2 copper layers, 112.8 x 83.1 mm, 53 parts (0 on the bottom side), 25 nets.

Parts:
C1: 225/400V; C_Rect_L24.0mm_W7.0mm_P22.50mm_MKT
C2, C7, C8: 104; C_Disc_D5.0mm_W2.5mm_P5.00mm
C3: 220uF/10V; CP_Radial_D6.3mm_P2.50mm
C4: 103; C_Disc_D5.0mm_W2.5mm_P5.00mm
C5: 100uF/25V; CP_Radial_D7.5mm_P2.50mm
C6: 330uF/35V; CP_Radial_D7.5mm_P2.50mm
C9, C10, C11: 0.1u/275V; C_Rect_L13.5mm_W5.0mm_P10.00mm_FKS3_FKP3_MKS4
D1, D2, D3, D4: 1N4148; D_DO-35_SOD27_P10.16mm_Horizontal
D5, D6, D7, D8: MUR460; D_DO-201AD_P12.70mm_Horizontal
DZ1: BZD23-C5V1; D_DO-41_SOD81_P10.16mm_Horizontal_Zener
FL1: Filter_EMI_LL; Choke_Schaffner_RN102-04-14.0x14.0mm
HS1: Heatsink_Pad_3Pin; heatsink
J1: EGS002; PinSocket_1x17_P2.54mm_Vertical
J2: FAN; JST_EH_B2B-EH-A_1x02_P2.50mm_Vertical
J3: Vin; JST_EH_B2B-EH-A_1x02_P2.50mm_Vertical
J4: L; TerminalBlock_MetzConnect_360381_1x01_Horizontal_ScrewM3.0
J5: N; TerminalBlock_MetzConnect_360381_1x01_Horizontal_ScrewM3.0
J6: VDD; TerminalBlock_MetzConnect_360381_1x01_Horizontal_ScrewM3.0
J7: GND; TerminalBlock_MetzConnect_360381_1x01_Horizontal_ScrewM3.0
L1: 3.3mH; L_Toroid_Vertical_L28.6mm_W14.3mm_P11.43mm_Bourns_5700
Q1, Q2, Q3, Q4: FGH40N60SFD; TO-247-3_Vertical
Q6: 2N2222A; TO-92_Inline_Wide
R1, R2, R3, R4, R12: 10k; R_Axial_DIN0207_L6.3mm_D2.5mm_P10.16mm_Horizontal
R5, R6, R7, R8: 4.7; R_Axial_DIN0207_L6.3mm_D2.5mm_P10.16mm_Horizontal
R10, R14: 100K; R_Axial_DIN0309_L9.0mm_D3.2mm_P12.70mm_Horizontal
R11, R11#2: 0.4; shun_L10mm
R16: 2.2K; R_Axial_DIN0207_L6.3mm_D2.5mm_P10.16mm_Horizontal
R17: NTC/10K; R_Axial_DIN0204_L3.6mm_D1.6mm_P2.54mm_Vertical
RV1: 10K; Potentiometer_RM065
U1: L7805; TO-220-3_Vertical
U2: L7812; TO-220-3_Vertical

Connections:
+5V: C3.1, C7.1 (+), J1.14, R17.1 (+), U1.3 (OUT)
+12V: C5.1, C8.1 (+), J1.12, J2.1, U1.1 (IN), U2.3 (OUT)
+VDC 400V: C10.1 (+), C11.1 (+), D5.1 (K), D6.1 (K), J6.1, Q1.2 (C), Q3.2 (C)
/FANCTR: J1.17, R16.1 (+)
/HO1: D4.1 (K), J1.6, R8.1 (+)
/HO2: D1.1 (K), J1.10, R5.1 (+)
/IFB: C10.2 (-), C11.2 (-), D7.2 (A), D8.2 (A), HS1.1, HS1.2, HS1.3, J1.1, Q2.3 (E), Q4.3 (E), R2.2 (-), R3.2 (-), R11.1, R11.2, R11#2.1, R11#2.2
/L: C9.1 (+), FL1.3, J4.1, R14.1 (+)
/LO1: D3.1 (K), J1.3, R7.1 (+)
/LO2: D2.1 (K), J1.8, R6.1 (+)
/N: C9.2 (-), FL1.1, J5.1
/TFB: C4.1 (+), J1.16, R17.2 (-)
/VFB: C2.1 (+), DZ1.1 (K), J1.15, R10.2 (-), R12.1 (+), RV1.2, RV1.3
/VS1: C1.2 (-), D6.2 (A), D8.1 (K), FL1.2, J1.5, Q3.3 (E), Q4.2 (C), R4.2 (-)
/VS2: D5.2 (A), D7.1 (K), J1.9, L1.1, Q1.3 (E), Q2.2 (C), R1.2 (-)
/Vin_supply: C6.1, J3.2, U2.1 (IN)
GND: C2.2 (-), C3.2, C4.2 (-), C5.2, C6.2, C7.2 (-), C8.2 (-), DZ1.2 (A), J1.2, J1.4, J1.7, J1.11, J1.13, J3.1, J7.1, Q6.1 (E), R11.3, R11.4, R11#2.3, R11#2.4, R12.2 (-), RV1.1, U1.2 (GND), U2.2 (GND)
unnamed: C1.1 (+), FL1.4, L1.2
unnamed: D1.2 (A), Q1.1 (G), R1.1 (+), R5.2 (-)
unnamed: D2.2 (A), Q2.1 (G), R2.1 (+), R6.2 (-)
unnamed: D3.2 (A), Q4.1 (G), R3.1 (+), R7.2 (-)
unnamed: D4.2 (A), Q3.1 (G), R4.1 (+), R8.2 (-)
unnamed: J2.2, Q6.3 (C)
unnamed: Q6.2 (B), R16.2 (-)
unnamed: R10.1 (+), R14.2 (-)

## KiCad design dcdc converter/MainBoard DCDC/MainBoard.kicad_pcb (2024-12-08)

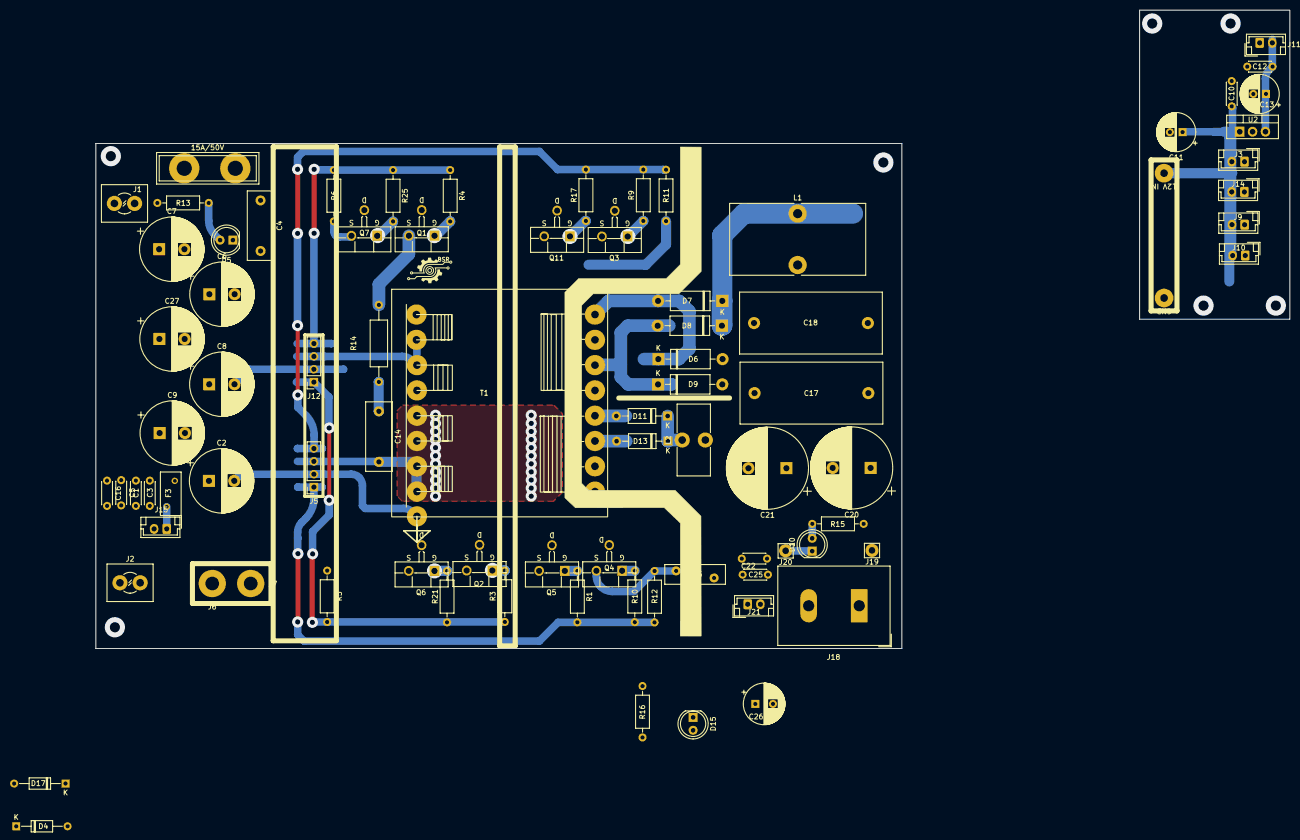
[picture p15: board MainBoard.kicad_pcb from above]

Board: 2 copper layers, 236.1 x 126.2 mm, 84 parts (0 on the bottom side), 35 nets.

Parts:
BSR: LOGO
C1, C3, C5, C10, C12, C16, C22, C25: 104; C_Disc_D4.3mm_W1.9mm_P5.00mm
C2, C6, C7, C8, C9, C27: 1000uF/50V; CP_Radial_D12.5mm_P5.00mm
C4, C14: 102/250V; C_Rect_L13.5mm_W5.0mm_P10.00mm_FKS3_FKP3_MKS4
C11: 100uF/25V; CP_Radial_D7.5mm_P2.50mm
C13: 220uF/10V; CP_Radial_D7.5mm_P2.50mm
C15: 102/1KV; RV_Disc_D12mm_W3.9mm_P7.5mm
C17, C18: 105/630V; C_Rect_L28.0mm_W12.0mm_P22.50mm_MKS4
C20, C21: 10uF/250V; CP_Radial_D16.0mm_P7.50mm
C26: 100uF/50V; CP_Radial_D8.0mm_P3.50mm
D4, D17: 1N4148; D_DO-35_SOD27_P10.16mm_Horizontal
D5, D10, D15: LED; LED_D5.0mm_Clear
D6, D7, D8, D9: MUR460; D_DO-15_P12.70mm_Horizontal
D11, D13: 1N5819; D_A-405_P10.16mm_Horizontal
F1: 15A/50V; fuse15A
F3: 0.75A/50V; Fuse_BelFuse_0ZRE0012FF_L8.3mm_W3.8mm
J1: +48VDC; TerminalBlock_MetzConnect_360291_1x01_Horizontal_ScrewM3.0_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
J2: GND; TerminalBlock_MetzConnect_360291_1x01_Horizontal_ScrewM3.0_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
J3, J9, J10, J14: 12V; JST_EH_B2B-EH-A_1x02_P2.50mm_Vertical
J5: Gate2; PinSocket_1x04_P2.54mm_Vertical
J6: GND; MountingHole_2.7mm_M2.5_Pad
J7: GNDsens; MountingHole_2.7mm_M2.5_Pad
J11: 5V; JST_EH_B2B-EH-A_1x02_P2.50mm_Vertical
J12: Gate1; PinSocket_1x04_P2.54mm_Vertical
J15: 48VDC; JST_EH_B2B-EH-A_1x02_P2.50mm_Vertical
J16: GND; 3.7mm Pin
J17: 12V IN; 3.7mm Pin
J18: 400VDC OUT; TerminalBlock_Dinkle_DT-55-B01X-02_P10.00mm
J19: 400VDC; Pin_D1.3mm_L11.3mm_W2.8mm_Flat
J20: GND; Pin_D1.3mm_L11.3mm_W2.8mm_Flat
J21: 24VDC; JST_EH_B2B-EH-A_1x02_P2.50mm_Vertical
L1: 3mH; L_Toroid_Vertical_L26.7mm_W14.0mm_P10.16mm_Pulse_D
L2: 100uH; L_Toroid_Vertical_L14.0mm_W6.3mm_P4.57mm_Pulse_A
Q1, Q2, Q3, Q4, Q5, Q6, Q7, Q11: IRFB4310; TO-220F-3_Staggered_Vertical_GDS
R1, R3, R4, R9, R10, R17, R21, R25: 10; R_Axial_DIN0207_L6.3mm_D2.5mm_P10.16mm_Horizontal
R5, R6, R11, R12, R13, R16: 10K; R_Axial_DIN0207_L6.3mm_D2.5mm_P10.16mm_Horizontal
R14: 330/1W; R_Axial_DIN0309_L9.0mm_D3.2mm_P15.24mm_Horizontal
R15: 100K; R_Axial_DIN0207_L6.3mm_D2.5mm_P10.16mm_Horizontal
T1: PQ3535
U2: L7805; TO-220-3_Vertical

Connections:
+5V: C12.2, C13.1, J11.2, U2.3 (OUT)
+12V: C10.2, C11.1, J3.2, J9.2, J10.2, J14.2, J17.1, U2.1 (IN)
+24V: C22.1, C25.1, C26.1, J21.1, L2.2, R16.1
/+48V In: C1.1, C3.1, C5.1, C7.1, C9.1, C16.1, C27.1, F1.1, F3.2, J1.1, R13.1
/+400VDC: C17.1, C18.1, C20.1, J18.1, J19.1, L1.2, R15.1
/GH1: J12.4, R4.1, R6.2, R25.1
/GH2: J5.4, R9.2, R11.2, R17.2
/GL1: J12.1, R3.1, R5.2, R21.1
/GL2: J5.1, R1.2, R10.2, R12.2
/VS1: C14.2, J5.3, J12.3, Q1.3 (S), Q2.2 (D), Q3.3 (S), Q4.2 (D), Q5.2 (D), Q6.2 (D), Q7.3 (S), Q11.3 (S), R6.1, R11.1, R14.2, T1.1, T1.2, T1.3, T1.4, T1.5, T1.6, T1.7, T1.8
GND: C1.2, C2.2, C3.2, C4.2, C5.2, C6.2, C8.2, C10.1, C11.2, C12.1, C13.2, C15.1, C16.2, D5.1 (K), J3.1, J5.2, J7.1, J9.1, J10.1, J11.1, J12.2, J14.1, J15.2, J16.1, Q2.3 (S), Q4.3 (S), Q5.3 (S), Q6.3 (S), R5.1, R12.1, T1.17 (GND), U2.2 (GND)
GND1: C15.2, C17.2, C18.2, C21.2, C22.2, C25.2, C26.2, D6.2 (A), D9.2 (A), D10.1 (K), D15.1 (K), J18.2, J20.1, J21.2, T1.10
unnamed: C2.1, C6.1, C7.2, C8.1, C9.2, C27.2
unnamed: C14.1, R14.1
unnamed: C20.2, C21.1
unnamed: D5.2 (A), R13.2
unnamed: D6.1 (K), D7.2 (A), T1.16
unnamed: D7.1 (K), D8.1 (K), L1.1
unnamed: D8.2 (A), D9.1 (K), T1.14
unnamed: D10.2 (A), R15.2
unnamed: D11.2 (A), T1.12
unnamed: D11.1 (K), D13.1 (K), L2.1
unnamed: D13.2 (A), T1.11
unnamed: D15.2 (A), R16.2
unnamed: J2.1, J6.1
unnamed: F3.1, J15.1
unnamed: Q1.1 (G), R4.2
unnamed: Q2.1 (G), R3.2
unnamed: Q3.1 (G), R9.1
unnamed: Q4.1 (G), R10.1
unnamed: Q5.1 (G), R1.1
unnamed: Q6.1 (G), R21.2
unnamed: Q7.1 (G), R25.2
unnamed: Q11.1 (G), R17.1
VDD: C4.1, F1.2, Q1.2 (D), Q3.2 (D), Q7.2 (D), Q11.2 (D)

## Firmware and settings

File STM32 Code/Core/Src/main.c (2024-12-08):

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
/* Includes ------------------------------------------------------------------*/
#include "main.h"

/* USER CODE BEGIN Includes */
#include <stdio.h>
#include "string.h"
#include "stm32f4xx_hal.h"

/* USER CODE END Includes */

ADC_HandleTypeDef hadc1;

TIM_HandleTypeDef htim1;
TIM_HandleTypeDef htim2;
DMA_HandleTypeDef hdma_tim1_ch1;
DMA_HandleTypeDef hdma_tim2_ch1;

UART_HandleTypeDef huart1;
DMA_HandleTypeDef hdma_usart1_tx;

void SystemClock_Config(void);
static void MX_GPIO_Init(void);
static void MX_DMA_Init(void);
static void MX_ADC1_Init(void);
static void MX_TIM1_Init(void);
static void MX_TIM2_Init(void);
static void MX_USART1_UART_Init(void);
/* USER CODE BEGIN 0 */
// Define PID Input
#define   kp 0.95f   // P Gain Input--good kp = 0.66f--New P = 0.60f
#define   ki 16.66f  // I Gain Input--good ki = 16.66f--New I = 10.725f
#define   kd 0.00f   // D Gain Input

// setPoint
float setpoint = 400.0f;

// Define PID limits
//maximum duty circle 690/2 = 345-Dead Time
//Haft Duty circle = 365.0f - (360ns) = 345
#define   PID_MIN_OUTPUT 0.0f
#define   PID_MAX_OUTPUT 330.0f //MAX 330 is good
// Define Kalman filter parameters
//for voltage feedback
#define   Q 0.01f // Process noise covariance
#define   R 0.5f  // Measurement noise covariance
//for current sensor
#define   Q1 0.01f // Process noise covariance
#define   R1 0.5f  // Measurement noise covariance
//for voltage sensor input
#define   Q2 0.01f // Process noise covariance
#define   R2 0.5f  // Measurement noise covariance

// Define anti-windup parameters
#define   INTEGRAL_MIN 0.0f
#define   INTEGRAL_MAX 800.0f

// Define Derivative clamp parameters
#define   tau 0.02

// ADC parameters
#define   ADC_MAX_VALUE 4095.0f // 12-bit ADC
#define   ADC_MIN_VALUE 0.0f

// Map function parameters
#define   INPUT_MIN 0.0f
#define   INPUT_MAX 5.0f  //500V = 5V

// PID Parameter
float error = 0.0f, last_error = 0.0f, proportional = 0.0f, integral = 0.0f,
		derivate = 0.0f;
float PID_out = 0.0f;
float out = 0.0f;
float PWM = 0.0f;
double input = 0.0f;
float last_feedback = 0.0f;
float UVout = 0.0f;
float Vin = 0.0f;
float Iout = 0.0f;
int UVref = 50.0f;
int Iref = 20.0f;   //Max 50A
int first_start_pwm = 40.0f; //first_start_pwm D12.5% = 83.25 ,D25% = 166.5, D45% = 333
float i = 0.0f;
int Iset = 30.0f;
float Pin = 0.0f;

char data[100];

#define   SAMPLE_TIME      10 	// 10 milliseconds
#define   SAMPLE_TIME1     10 	// 10 milliseconds
float dt = 0.0f; 		// Time interval between control loop iterations
float dt1 = 0.0f;
uint32_t last_time = 0.0f;
uint32_t current_time;
uint32_t now;
uint32_t last;

float previousMillis = 0.0f;
float interval = 100.0f;

/*-----------------------------map value------------------------------------*/
float map(float x, float in_min, float in_max, float out_min, float out_max) {
	return (x - in_min) * (out_max - out_min) / (in_max - in_min) + out_min;
}
float map1(float x1, float in_min1, float in_max1, float out_min1, float out_max1) {
	return (x1 - in_min1) * (out_max1 - out_min1) / (in_max1 - in_min1) + out_min1;
}
float map2(float x2, float in_min2, float in_max2, float out_min2, float out_max2) {
	return (x2 - in_min2) * (out_max2 - out_min2) / (in_max2 - in_min2) + out_min2;
}
float map3(float x3, float in_min3, float in_max3, float out_min3, float out_max3) {
	return (x3 - in_min3) * (out_max3 - out_min3) / (in_max3 - in_min3) + out_min3;
}
/*--------------------------------------------------------------------------*/

/*------------------------------kalman_filter-------------------------------*/
float kalman_filter1(float measurement1, float dt1) {
	static float x_Est1 = 0.0f; // State estimate
	static float P1 = 1.0f;     // Estimate covariance
	static float H1 = 1.0f;  // Measurement matrix
	static float F1 = 1.0f;  // State transition matrix

	// Prediction
	float x_est_minus1 = F1 * x_Est1;
	float P_minus1 = P1 + Q1 * dt1;

	// Update
	float K1 = (P_minus1 * H1)/(H1 * P_minus1 + R1);
	x_Est1 = x_est_minus1 + K1 * (measurement1 - x_est_minus1);
	P1 = (1 - K1 * H1) * P_minus1;
	return x_Est1;
}

float kalman_filter2(float measurement2, float dt1) {
	static float x_Est2 = 0.0f; // State estimate
	static float P2 = 1.0f;     // Estimate covariance
	static float H2 = 1.0f;  // Measurement matrix
	static float F2 = 1.0f;  // State transition matrix

	// Prediction
	float x_est_minus2 = F2 * x_Est2;
	float P_minus2     = F2 * P2 + Q2 * dt1;

	// Update
	float K2 = (P_minus2 * H2)/(H2 * P_minus2 + R2);
	x_Est2 = x_est_minus2 + K2 * (measurement2 - H2 * x_est_minus2);
	P2 = (1 - K2 * H2) * P_minus2;
	return x_Est2;
}

// Function to update the Kalman filter
float Kalman_Update(float z, float delta) {
	// Kalman filter variables
	static float x = 0.0f;  // State estimate
	static float P = 1.0f;  // Estimate covariance
	static float H = 1.0f;  // Measurement matrix
	static float F = 1.0f;  // State transition matrix

	// Prediction step
	float x_pred = F * x;
	float P_pred = F * P + Q * delta;

	// Update step
	float K = P_pred * H / (H * P_pred + R);  // Kalman gain
	x = x_pred + K * (z - H * x_pred);
	P = (1 - K * H) * P_pred;
	return x;
}

/*------------------------PID COMPUTE---------------------------------------*/
void PID_comput(float setPoint, float feedback) {
	setPoint = map(setPoint, 0.0f, 500.0f, 0.0f, 330);
	feedback = map(feedback, 0.0f, 500.0f, 0.0f, 330);
	error = setPoint - feedback;

	proportional = kp * error; //Proportional--------------------------------------------------

	/* Integral term with ANTI WIND-UP */

	integral += ( ki * dt * error); // integral += ((ki * error) * dt);-----------
	if (integral > INTEGRAL_MAX) {
		integral = INTEGRAL_MAX / ki; //integral = INTEGRAL_MAX/ki;
	} else if (integral < INTEGRAL_MIN) {
		integral = INTEGRAL_MIN / ki; // integral = INTEGRAL_MIN/ki;
	}

	//-------------------------------------

	/* Derivative (band-limited differentiator)*/

	//derivate = kd * ((error - last_error)/dt);
	derivate = -(2.0f * kd * (feedback - last_feedback)/* Note: derivative on measurement, therefore minus sign in front of equation! */
	+ (2.0f * tau - dt) * derivate) / (2.0f * tau + dt);
	//-------------------------------------

	PID_out = proportional + integral + derivate; //PID OUTPUT

	/*Output Limit-------------------------*/
	if (PID_out > PID_MAX_OUTPUT) {
		integral -= (ki * error * dt); // integral =  integral + (ki * error);
		PID_out = PID_MAX_OUTPUT;
	} else if (PID_out < PID_MIN_OUTPUT) {
		//integral += (ki * error * dt);
		PID_out = PID_MIN_OUTPUT;
	}
	last_error = error;
	last_feedback = feedback;
	//------------------------------
	//return PID_out;
}
//------------------------UART Serial Print Data-----------------------------------------------------------------------------------------------------------------------------------------
void print_data(float IN1, float IN2, float IN3, float IN4, float IN5,
		float IN6, float IN7) {
	// Blink the status LED
	unsigned long currentMillis = HAL_GetTick();
	if (currentMillis - previousMillis >= interval) {
		previousMillis = currentMillis;
		sprintf(data,
				"I:%.2fA  Vf:%.2fV  PWM:%.2f  Pin:%.2fW  ut:%.2f  Targ:%.fV  Vin:%.2fV \r\n",
				IN1, IN2, IN3, IN4, IN5, IN6, IN7);
		HAL_UART_Transmit(&huart1, (uint8_t*) data, strlen(data),
				HAL_MAX_DELAY);
	}
}
//---------------------------------------------------------------------------------------------------------------------------------------------------------------------------------
void ADC_Select_CH0(void) {
	ADC_ChannelConfTypeDef sConfig = { 0 };
	/** Configure for the selected ADC regular channel its corresponding rank in the sequencer and its sample time.
	 */
	sConfig.Channel = ADC_CHANNEL_0;
	sConfig.Rank = 1;
	sConfig.SamplingTime = ADC_SAMPLETIME_84CYCLES;
	if (HAL_ADC_ConfigChannel(&hadc1, &sConfig) != HAL_OK) {
		Error_Handler();
	}
}

void ADC_Select_CH1(void) {
	ADC_ChannelConfTypeDef sConfig = { 0 };
	/** Configure for the selected ADC regular channel its corresponding rank in the sequencer and its sample time.
	 */
	sConfig.Channel = ADC_CHANNEL_1;
	sConfig.Rank = 1;
	sConfig.SamplingTime = ADC_SAMPLETIME_112CYCLES;
	if (HAL_ADC_ConfigChannel(&hadc1, &sConfig) != HAL_OK) {
		Error_Handler();
	}
}

void ADC_Select_CH2(void) {
	ADC_ChannelConfTypeDef sConfig = { 0 };
	/** Configure for the selected ADC regular channel its corresponding rank in the sequencer and its sample time.
	 */
	sConfig.Channel = ADC_CHANNEL_2;
	sConfig.Rank = 1;
	sConfig.SamplingTime = ADC_SAMPLETIME_144CYCLES;
	if (HAL_ADC_ConfigChannel(&hadc1, &sConfig) != HAL_OK) {
		Error_Handler();
	}
}

void ADC_Select_CH3(void) {
	ADC_ChannelConfTypeDef sConfig = { 0 };
	/** Configure for the selected ADC regular channel its corresponding rank in the sequencer and its sample time.
	 */
	sConfig.Channel = ADC_CHANNEL_3;
	sConfig.Rank = 1;
	sConfig.SamplingTime = ADC_SAMPLETIME_28CYCLES;
	if (HAL_ADC_ConfigChannel(&hadc1, &sConfig) != HAL_OK) {
		Error_Handler();
	}
}

void ADC_Select_CH4(void) {
	ADC_ChannelConfTypeDef sConfig = { 0 };
	/** Configure for the selected ADC regular channel its corresponding rank in the sequencer and its sample time.
	 */
	sConfig.Channel = ADC_CHANNEL_4;
	sConfig.Rank = 1;
	sConfig.SamplingTime = ADC_SAMPLETIME_15CYCLES;
	if (HAL_ADC_ConfigChannel(&hadc1, &sConfig) != HAL_OK) {
		Error_Handler();
	}
}

/* USER CODE END 0 */

/**
  * @brief  The application entry point.
  * @retval int
  */
int main(void)
{

  /* MCU Configuration--------------------------------------------------------*/

  /* Reset of all peripherals, Initializes the Flash interface and the Systick. */
  HAL_Init();

  /* Configure the system clock */
  SystemClock_Config();

  /* Initialize all configured peripherals */
  MX_GPIO_Init();
  MX_DMA_Init();
  MX_ADC1_Init();
  MX_TIM1_Init();
  MX_TIM2_Init();
  MX_USART1_UART_Init();
  /* USER CODE BEGIN 2 */

	HAL_TIM_PWM_Start(&htim1, TIM_CHANNEL_1);	//Pin PA8
	HAL_TIM_OC_Start(&htim1, TIM_CHANNEL_2);
	HAL_TIM_PWM_Start(&htim2, TIM_CHANNEL_1);	//Pin PA5

  /* USER CODE END 2 */

  /* Infinite loop */
  /* USER CODE BEGIN WHILE */
	uint32_t adc_value[5];

	while (1) {

		ADC_Select_CH0();            //ADC1 CHANNEL0(PA0)
		HAL_ADC_Start(&hadc1);
		HAL_ADC_PollForConversion(&hadc1, 100);
		adc_value[0] = HAL_ADC_GetValue(&hadc1);
		HAL_ADC_Stop(&hadc1);

		ADC_Select_CH1();            //ADC1 CHANNEL1(PA1)
		HAL_ADC_Start(&hadc1);
		HAL_ADC_PollForConversion(&hadc1, 100);
		adc_value[1] = HAL_ADC_GetValue(&hadc1);
		HAL_ADC_Stop(&hadc1);

		ADC_Select_CH2();            //ADC1 CHANNEL0(PA2)
		HAL_ADC_Start(&hadc1);
		HAL_ADC_PollForConversion(&hadc1, 100);
		adc_value[2] = HAL_ADC_GetValue(&hadc1);
		HAL_ADC_Stop(&hadc1);

		ADC_Select_CH3();            //ADC1 CHANNEL0(PA3)
		HAL_ADC_Start(&hadc1);
		HAL_ADC_PollForConversion(&hadc1, 100);
		adc_value[3] = HAL_ADC_GetValue(&hadc1);
		HAL_ADC_Stop(&hadc1);

		ADC_Select_CH4();            //ADC1 CHANNEL0(PA4)
		HAL_ADC_Start(&hadc1);
		HAL_ADC_PollForConversion(&hadc1, 100);
		adc_value[4] = HAL_ADC_GetValue(&hadc1);
		HAL_ADC_Stop(&hadc1);

//------------------------------------------------------------
		//voltage feedback map value of ADC1(PA0)
		input = map(adc_value[0], ADC_MIN_VALUE, ADC_MAX_VALUE, INPUT_MIN,
				INPUT_MAX);
		float Vfeedback = ((input - 0.29f) * 125.0f) / 1.079f;	      //117
		if (Vfeedback > 600.0f) {
			Vfeedback = 600.0;
		} else if (Vfeedback < 0.0f) {
			Vfeedback = 0.0f;
		}
//-----------------------------------------------------------------------------------
		//current feedback map value of ADC1(PA1)
		Iout = map1(adc_value[1], 0.0f, 4095.0f, 0.0f, 5.0f);
		Iout = (Iout - (2.427f)) / 0.040f;	 //convert voltage to current 40mV/A
		if (Iout >= 60.0f) {
			Iout = 60.0f;
		} else if (Iout < 0.0f) {
			Iout = 0.0f;
		}

//-----------------------------------------------------------------------------------
		//V_input feedback map value of ADC1(PA2)
		Vin = map2(adc_value[2], 0.0f, 4095.0f, 0.0f, 103.4f);

//-----------------------------------------------------------------------------------
		// Run filter
		float filtered1 = Kalman_Update(Vfeedback, dt1);
	    float filtered2 = kalman_filter1(Iout,dt1);
	    float filtered3 = kalman_filter2(Vin,dt1);

		now = HAL_GetTick();
		dt1 = (now - last) / 1000.0f; // Convert ms to seconds
		if (dt1 >= (SAMPLE_TIME1 / 1000.0f)) {

			last = now; // Update last
		}
		current_time = HAL_GetTick();
		dt = (current_time - last_time) / 1000.0f; // Convert ms to seconds
		if (dt >= (SAMPLE_TIME / 1000.0f)) {
			//-------------------------------------------------------------------------

			PID_comput(setpoint, filtered1); //PID_comput(setPoint, Input);
			//PI_comput(Iset, filtered2); //P_comput(setPoint, Input) For current
			last_time = current_time; // Update last_time
		}

		Pin = filtered2 * filtered3;//calculate output power

		PWM = PID_out; // Otherwise, use voltage control

//----------------Timer PWM Generator--------------------------
		TIM1->CCR1 = PWM;
		TIM2->CCR1 = PWM;
//-------------------------------------------------------------
		if (i < 1) {
			HAL_GPIO_WritePin(GPIOC, GPIO_PIN_13, GPIO_PIN_SET);
			HAL_Delay(300);
			HAL_GPIO_WritePin(GPIOC, GPIO_PIN_13, GPIO_PIN_RESET);
		}
//--------------------------PWM SHUT DOWN----------------------
		if ((Vin >= 60) || (Vin <= 40)) {//When batteries are Higher or Lower than reference, System will be shut down
			HAL_TIM_PWM_Stop(&htim1, TIM_CHANNEL_1);
			HAL_TIM_PWM_Stop(&htim2, TIM_CHANNEL_1);
			HAL_GPIO_WritePin(GPIOB, GPIO_PIN_13, GPIO_PIN_SET);
			while (1) {
				HAL_GPIO_WritePin(GPIOC, GPIO_PIN_13, GPIO_PIN_SET);
				HAL_Delay(1000);
				HAL_GPIO_WritePin(GPIOC, GPIO_PIN_13, GPIO_PIN_RESET);
				HAL_Delay(1000);

				if ((Vin < 60) || (Vin > 46)) {//When batteries are normal, System will be reset
					NVIC_SystemReset();//Automatic system reset
					break;
				}
			}
		}
//-------------------------------------------------------------

		if (filtered2 >= Iref) {// Overload Current
			HAL_TIM_PWM_Stop(&htim1, TIM_CHANNEL_1);
			HAL_TIM_PWM_Stop(&htim2, TIM_CHANNEL_1);
			HAL_GPIO_WritePin(GPIOB, GPIO_PIN_13, GPIO_PIN_SET);
			while (1) {

				HAL_GPIO_WritePin(GPIOC, GPIO_PIN_13, GPIO_PIN_SET);
				HAL_Delay(300);
				HAL_GPIO_WritePin(GPIOC, GPIO_PIN_13, GPIO_PIN_RESET);
				HAL_Delay(300);

			}

		}
		//-----------------------------------------------------------
		print_data(filtered2, filtered1, PWM, Pin, PID_out, setpoint, filtered3);

//soft start-----------------------------------------------------------------------------------------------------------
		while (i <= first_start_pwm) {
			i += 0.0002f;

			filtered1 = Kalman_Update(Vfeedback, dt1);
			filtered2 = kalman_filter1(Iout, dt1);
			filtered3 = kalman_filter2(Vin, dt1);
			PID_comput(setpoint, filtered1); //PID_comput(setPoint, Input);
//					 PI_comput(Iset, filtered2); //P_comput(setPoint, Input) For current
			TIM1->CCR1 = i;
			TIM2->CCR1 = i;
			print_data(filtered2, filtered1, i, Pin, PID_out, setpoint, filtered3);
			if (i == first_start_pwm) {
				break;
			}
		}
//--------------------------------------------------------------------------------------------------------------------

    /* USER CODE END WHILE */

    /* USER CODE BEGIN 3 */
	}
  /* USER CODE END 3 */
}

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


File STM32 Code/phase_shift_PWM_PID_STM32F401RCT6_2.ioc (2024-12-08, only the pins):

Mcu.UserName=STM32F401RCTx
PA0-WKUP.Signal=ADCx_IN0
PA1.Signal=ADCx_IN1
PA10.Signal=USART1_RX
PA13.Signal=SYS_JTMS-SWDIO
PA14.Signal=SYS_JTCK-SWCLK
PA2.Signal=ADCx_IN2
PA3.Signal=ADCx_IN3
PA4.Signal=ADCx_IN4
PA5.Signal=S_TIM2_CH1_ETR
PA8.Signal=S_TIM1_CH1
PA9.Signal=USART1_TX
PB0.Signal=GPIO_Input
PB1.Signal=GPIO_Input
PB10.Signal=GPIO_Input
PB12.Signal=GPIO_Output
PB13.Signal=GPIO_Output
PB14.Signal=GPIO_Output
PB15.Signal=GPIO_Output
PB2.Signal=GPIO_Input
PC13-ANTI_TAMP.Signal=GPIO_Output
PC14-OSC32_IN.Signal=RCC_OSC32_IN
PC15-OSC32_OUT.Signal=RCC_OSC32_OUT

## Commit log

2024-12-08 Create stm32
2024-12-08 Create RELAY 40A
2024-12-08 Create Isolated voltage sensor

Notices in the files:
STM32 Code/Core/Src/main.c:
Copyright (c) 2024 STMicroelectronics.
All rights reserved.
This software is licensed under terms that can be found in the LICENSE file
